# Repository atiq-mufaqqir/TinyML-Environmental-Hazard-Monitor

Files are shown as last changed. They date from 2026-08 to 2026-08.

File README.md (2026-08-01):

# TinyML-Based Indoor Environmental Monitoring System

## Overview

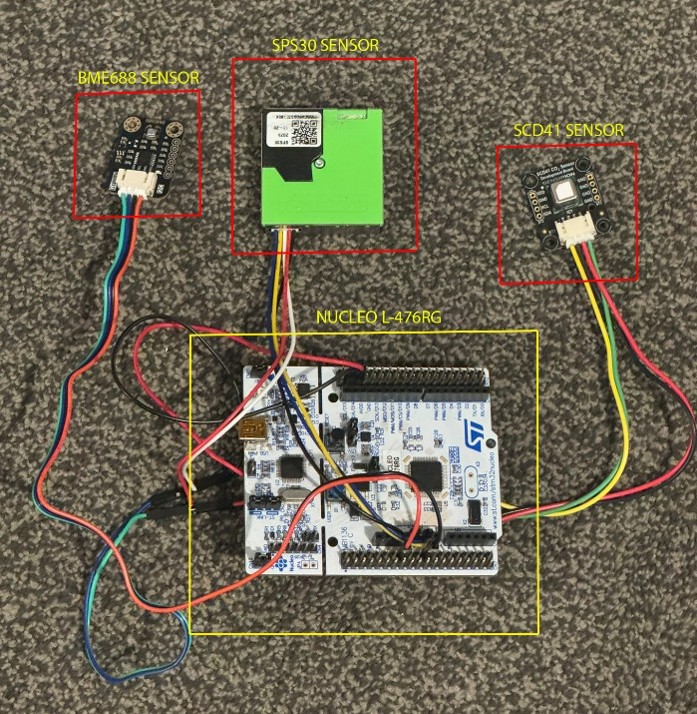
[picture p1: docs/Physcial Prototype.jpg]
Physical Prototype


This project develops a low-cost embedded indoor environmental monitoring system using **multi-sensor fusion and TinyML-based classification**.

The system uses an **STM32 Nucleo-L476RG microcontroller** to collect environmental data from multiple sensors, process the data locally, and classify indoor conditions in real time.

Unlike traditional threshold-based air-quality monitoring systems, this project uses machine learning to identify patterns across multiple environmental parameters and classify different indoor events:

- Normal background conditions
- Cooking activity
- Aerosol spray usage

The trained TinyML model is deployed directly onto the STM32 microcontroller, enabling real-time edge inference without cloud processing.

---

# Key Features

- Real-time environmental monitoring
- Multi-sensor data fusion
- STM32 embedded firmware development
- TinyML neural network deployment
- Local machine learning inference
- UART-based live monitoring
- Dataset collection and processing
- Custom PCB design using KiCad

---

# System Architecture

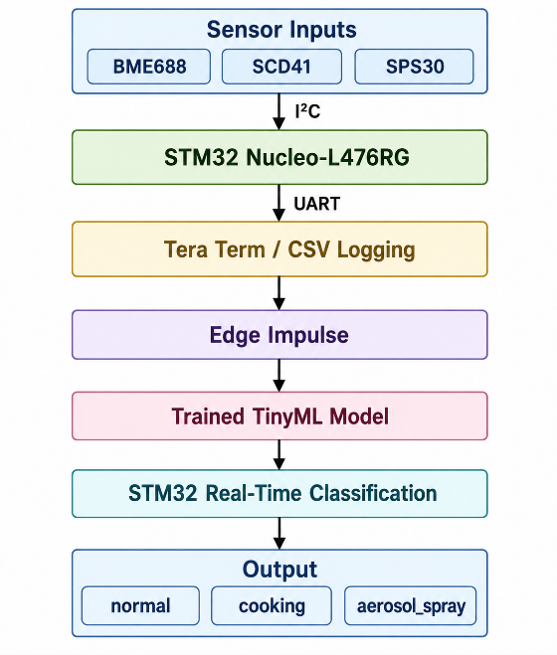
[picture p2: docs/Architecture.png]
System Architecture


# Hardware Components

## STM32 Nucleo-L476RG

The STM32 Nucleo-L476RG was selected as the embedded processing platform.

Features used:

- ARM Cortex-M4 processor
- STM32CubeIDE development environment
- STM32 HAL libraries
- I2C communication
- UART communication
- Embedded TinyML inference

---

# Environmental Sensors

## Bosch BME688

Measurements:

- Temperature
- Humidity
- Pressure
- Gas resistance

Purpose:

- Detect environmental and gas-related changes caused by indoor activities.

---

## Sensirion SCD41

Measurement:

- Carbon dioxide (CO₂)

Purpose:

- Provides ventilation and occupancy-related information.

---

## Sensirion SPS30

Measurements:

- PM1.0
- PM2.5
- PM4.0
- PM10
- Particle number concentration

Purpose:

- Detects particulate changes caused by cooking and aerosol events.

---

# Hardware Communication

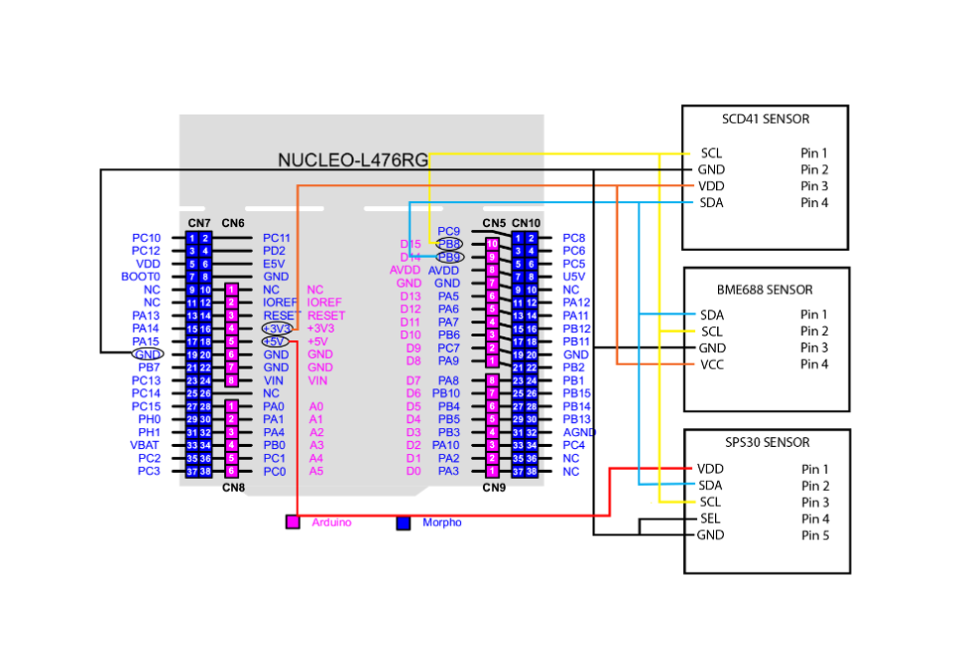
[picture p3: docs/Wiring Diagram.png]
Hardware Connection


| Component | Interface | STM32 Connection |
|---|---|---|
| BME688 | I2C | PB8/PB9 |
| SCD41 | I2C | PB8/PB9 |
| SPS30 | I2C | PB8/PB9 |
| PC Logging | UART | USART2 |

Communication settings:

```
I2C Speed: 100 kHz
UART Baud Rate: 115200
Sampling Interval: 5 seconds
```

---

# Firmware Development

The firmware was developed using:

- STM32CubeIDE
- STM32CubeMX
- STM32 HAL Drivers

## Firmware Workflow

1. Initialise STM32 peripherals
2. Configure I2C and UART communication
3. Detect connected sensors
4. Initialise sensor drivers
5. Read sensor measurements
6. Format sensor data
7. Output data through UART
8. Run TinyML classification

---

# Dataset Collection

A custom dataset was collected in a domestic kitchen environment.

The system was trained to classify three indoor conditions:

| Class | Description |
|---|---|
| Normal | Background indoor conditions |
| Cooking | Frying activity using an induction hob |
| Aerosol | Deodorant and air freshener spray |

## Dataset Summary

| Class | Number of Readings | Duration |
|---|---|---|
| Normal | 5267 | ~439 minutes |
| Cooking | 879 | ~73 minutes |
| Aerosol | 352 | ~29 minutes |

Sampling interval:

```
One reading every 5 seconds
```

---

# TinyML Model Development

The machine learning model was developed using **Edge Impulse**.

## Model Configuration

Input:

- 15 sensor features
- 60 second time windows
- 180 input features

Neural network:

```
Input Layer
      |
Dense Layer (20 neurons)
      |
Dense Layer (10 neurons)
      |
Output Layer (3 classes)
```

Classes:

```
0 - Aerosol
1 - Cooking
2 - Normal
```

---

# Model Performance

## Training Results

| Metric | Result |
|---|---|
| Training Accuracy | 99.06% |
| Validation Accuracy | 100% |
| Validation Loss | 0.0202 |

---

# Embedded Deployment

The trained model was exported as an embedded C/C++ library and deployed onto the STM32 microcontroller.

Deployment results:

| Resource | Usage |
|---|---|
| Model Type | int8 Quantised Neural Network |
| RAM Usage | 1.6 KB |
| Flash Usage | 17.8 KB |
| Estimated Latency | 1 ms |

---

# Real-Time Classification

The final STM32 prototype successfully performed live classification.

Example output:

```
CO2: 650 ppm
PM2.5: 14 ug/m3
Gas Resistance: 42000 Ohm

Prediction:
NORMAL

Confidence:
96%
```

Testing results:

| Condition | Result |
|---|---|
| Normal Room | Correct |
| Cooking | Correct |
| Aerosol Spray | Correct |

---

# PCB Design

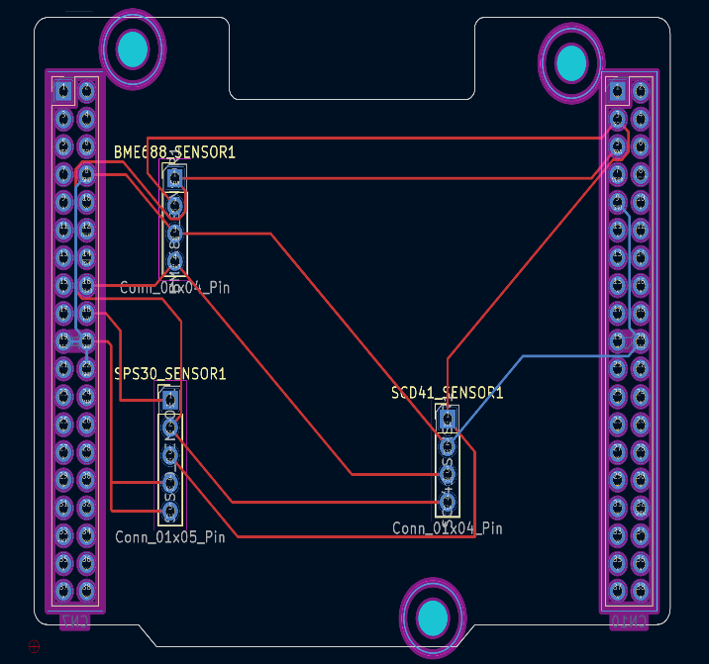
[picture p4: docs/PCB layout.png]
PCB Layout


A custom PCB was designed using **KiCad** to improve hardware integration.

Design process:

- Schematic capture
- Component selection
- PCB layout
- Routing
- Electrical Rule Check (ERC)
- Design Rule Check (DRC)

PCB features:

- STM32 interface
- Sensor connectors
- 3.3V and 5V power distribution
- Modular sensor connections

---

# Repository Structure

```
│
├── Core/
│ ├── Inc/
│ └── Src/
│ └── STM32 application firmware
│
├── Drivers/
│ └── STM32 HAL libraries and sensor drivers
│
├── Release/
│ └── Compiled firmware build files
│
├── docs/
│ └── Project documentation and images
│
├── media/
│ └── Project demonstration images/videos
│
├── ml/
│ ├── Dataset/
│ ├── Edge_Impulse/
│ └── Model training files
│
├── pcb/
│ └── KiCad schematic and PCB design files
│
├── TEST.ioc
│ └── STM32CubeMX configuration file
│
├── .project
├── .cproject
│
├── STM32L476RGTX_FLASH.ld
├── STM32L476RGTX_RAM.ld
│
└── README.md
```

---

# Technologies Used

## Embedded Systems

- STM32 Nucleo-L476RG
- ARM Cortex-M4
- STM32CubeIDE
- STM32 HAL
- I2C
- UART

## Sensors

- Bosch BME688
- Sensirion SCD41
- Sensirion SPS30

## Machine Learning

- TinyML
- Edge Impulse
- Neural Networks
- int8 Quantisation

## Hardware Design

- KiCad
- PCB Design
- Embedded Hardware Integration

---

# Limitations

Current limitations:

- Dataset collected from one indoor environment
- Limited aerosol training samples
- Sensor behaviour may vary between locations
- Not a certified air-quality or safety monitoring device
- PCB designed but not manufactured

---

# Future Improvements

Potential improvements:

- Collect larger datasets from different environments
- Add more indoor activity classes
- Add wireless connectivity (BLE/Wi-Fi)
- Develop mobile monitoring application
- Create battery-powered version
- Manufacture and test the PCB
- Compare against traditional threshold systems

---

# Project Outcome

This project demonstrates the use of **TinyML for intelligent embedded environmental monitoring** by combining:

- Sensor fusion
- Embedded firmware
- Machine learning
- Edge inference
- Hardware design

The final prototype successfully collected environmental data, trained a classification model, deployed the model onto an STM32 microcontroller, and performed real-time indoor condition classification.

---

# Author

Atiq Mufaqqir

## License

This project is intended for educational purposes as part of the ELEC3875 Individual Engineering Project.

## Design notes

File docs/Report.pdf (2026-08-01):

## Table of Contents

## List of Figures

Figure 2-1: System architecture of the TinyML-based indoor environmental monitoring

system | 9
Figure 2-2: Wiring diagram of the STM32 Nucleo-L476RG sensor system | 12

Figure 2-3: Physical prototype of the TinyML indoor environmental monitoring system......13

Figure 2-4: Tera Term output reading sensor values | 15
Figure 2-5: Logged dataset CSV format | 15
Figure 2-6: Firmware initialisation | 16
Figure 2-7: Kitchen Mockup | 16
Figure 2-8: Labelled and cleaned CSV dataset prepared for Edge Impulse | 18
Figure 2-9: Edge Impulse confusion matrix for the trained int8 classifier | 22
Figure 2-10: Tera Term live classification output from the final STM32 prototype | 23
Figure 2-11: KiCad schematic design and PCB layout | 24
Figure 2-12: KiCad 3D view of the proposed PCB design | 25

## List of Tables

Table 2-1: Sensor Operating Ranges | 11
Table 2-2: Sensor role in the sensing platform | 11
Table 2-3: Final Sensor Connections | 12
Table 2-4: STM32 communication configuration | 13
Table 2-5: Dataset collection conditions | 17
Table 2-6: Final labelled dataset summary | 18
Table 2-7: Embedded real-time inference workflow | 20
Table 2-8: Edge Impulse int8 deployment profiling results | 20
Table 2-9: TinyML model training and validation results | 21
Table 2-10: Validation confusion matrix | 22
Table 2-11: Real-time prototype testing results | 23

## 1 INTRODUCTION

### 1.1 Background

People spend a large proportion of their time indoors. Although indoor spaces are often

considered safe, they can contain pollution sources, including cooking, cleaning products,

aerosol sprays, and inadequate ventilation. The United States Environmental Protection

Agency states that indoor air-quality problems are often caused by indoor sources that release

gases or particles, while poor ventilation can allow pollutants to accumulate indoors [1].

Particulate matter is one of the main pollutants considered in this project. Fine particles can

remain suspended in air for long periods and can be inhaled deep into the respiratory system.

The World Health Organization identifies exposure to fine particulate matter as a major

environmental health risk [2]. Cooking is a common indoor source of particulate matter,

particularly during frying, heating, or food preparation. Even when an induction hob is used,

cooking can still produce fine particles that may affect indoor air quality over time [3].

Volatile organic compounds (VOCs) are also relevant because they can be released from

household products such as air fresheners, paints, sprays, and cleaning products. The EPA

notes that VOC concentrations can be higher indoors than outdoors and can be influenced by

product use and ventilation conditions [4]. Aerosol spray usage is therefore a relevant indoor

activity to monitor because it can create short-term changes in gas-related and particle-related

sensor readings.

Carbon dioxide is another important indoor measurement. Although CO₂ is not normally

treated as a direct pollutant at typical indoor levels, increased indoor CO₂ can indicate

reduced ventilation, higher occupancy, or limited air exchange with the outdoor environment

[5]. Monitoring CO₂ together with particulate matter, temperature, humidity, and gas-

resistance data can provide a wider understanding of the indoor environment.

Traditional air-quality monitoring systems often use fixed thresholds. These systems usually

trigger an alarm when a single measurement exceeds a predefined limit. Although useful for

basic monitoring, they do not always identify the cause of an air-quality change. For example,

cooking and aerosol spray events may both increase particle concentration or affect gas-

related readings, even though the sources are different. Previous research explains that air-

quality data often involves several pollutant and environmental variables, and that machine-

learning methods can identify complex relationships within structured sensor datasets [6].

Therefore, because indoor activities can produce overlapping sensor responses, a

classification-based approach may be more useful than fixed thresholds.

This project investigates whether a low-cost embedded device can be made context-aware by

classifying indoor conditions in real time. Machine learning is suitable because indoor

environmental data includes several related variables that change over time. A practical

method is TinyML, where a lightweight machine-learning model is deployed directly onto a

microcontroller for local inference.

### 1.2 Current State of the Art

A key development in embedded environmental monitoring is the use of TinyML. TinyML

allows machine-learning models to run on resource-constrained microcontrollers instead of

relying on cloud processing. This can reduce latency, improve privacy, and allow the system

to operate in real time with limited memory, processing power, and energy. Ray describes

TinyML as a shift from high-power machine-learning systems towards low-end edge devices,

while also highlighting challenges such as accuracy, reliability, and hardware limitations [7].

Recent work has shown that TinyML can be applied to air-quality monitoring. Wardana et al.

demonstrated that TinyML models can be deployed on a low-cost air-quality monitoring

device to perform prediction and data-imputation tasks on a microcontroller [8]. Platforms

such as Edge Impulse also support the training, testing, optimisation, and deployment of

embedded machine-learning models to microcontroller platforms.

However, many low-cost air-quality systems still rely mainly on fixed thresholds. These

systems are simple and affordable, but they provide limited information about the type of

event taking place. Cooking, aerosol spray use, cleaning product use, and poor ventilation

may affect several measurements at the same time and may produce similar sensor responses.

As a result, a fixed-threshold system may detect that an environmental change has occurred,

but it may not reliably classify the source.

### 1.3 Problem Statement

The problem addressed in this project is the need for a low-cost embedded system that can

measure indoor environmental conditions and classify the type of condition in real time.

Existing threshold-based systems can detect when a measurement increases above a set value,

but they may not provide enough context to distinguish between different indoor activities.

This project therefore focuses on developing a prototype system that uses multiple environmental sensors and TinyML classification to identify normal background, cooking,

and aerosol spray conditions.

### 1.4 Aim and Objectives

The aim of this project is to design, implement, and evaluate a TinyML-based embedded

indoor environmental monitoring system that can classify normal background, cooking, and

aerosol spray conditions in real time using data from multiple sensors.

The objectives of this project are:

- To investigate indoor air-quality changes during normal background, cooking, and

aerosol spray conditions.

- To develop an STM32-based embedded device for collecting environmental sensor

data.

- To collect and label datasets for the selected indoor conditions.
- To prepare the collected data for machine-learning training.
- To train and evaluate a TinyML model using Edge Impulse.
- To deploy the trained model onto the STM32 platform for real-time classification.
- To assess the system performance, constraints, and classification results.
- To discuss the limitations of the system and identify possible improvements.

### 1.5 Scope and Limitations

This project focuses on the development of a prototype rather than a certified commercial air-

quality monitor. The system is designed to classify three conditions only: normal background,

cooking, and aerosol spray usage. These classes were selected because they represent

common indoor activities and can produce measurable changes in environmental sensor

readings.

The system does not directly measure every possible indoor pollutant. It should not be

considered a professional regulatory monitoring device, a medical device, or a safety-critical

alarm system. The purpose is to classify indoor conditions based on sensor patterns over time,

rather than to determine whether legal exposure limits have been exceeded.

Several technical issues may also affect the system. These include sensor stability, reliable

sensor integration, dataset size, labelling accuracy, and the delay between an activity ending

and the sensor readings returning to normal. For example, particle or gas readings may

remain elevated for several minutes after cooking or aerosol spray usage, making accurate labelling more difficult. The deployed model must also fit within the memory and processing

constraints of the STM32 microcontroller.

### 1.6 Possible Applications

A TinyML-based indoor monitoring system could be used as an air-quality awareness device

in homes, kitchens, offices, and shared indoor spaces. It could provide ventilation feedback,

support smart kitchen monitoring, or help users understand how everyday activities affect

indoor air quality. With a larger dataset, similar systems could also be useful in busy indoor

environments. It can also be used as hazard monitoring system to detect the signs of early

hazards if trained with proper data.

### 1.7 Project Contribution

The main contribution of this project is the design and implementation of a low-cost STM32-

based indoor environmental monitoring prototype that uses TinyML for real-time

classification. The project also contributes a labelled dataset collected under normal

background, cooking, and aerosol spray conditions. This dataset is used to evaluate whether

low-cost sensors and embedded machine learning can distinguish between overlapping indoor

events.

## 2 TECHNICAL WORK

### 2.1 Literature Review

Wardana et al. [8] demonstrate how TinyML can be used to improve low-cost air quality

monitoring by deploying machine learning models directly on a resource-constrained

microcontroller. Their work is important because it shows that embedded devices can support

predictive and intelligent environmental monitoring while maintaining low power

consumption, low latency, and reduced dependence on cloud processing. The system used

sensor data such as CO₂, temperature, humidity, and electrical power parameters, collected

over a three-month period at 10-minute intervals. The data was pre-processed, standardised,

and scaled so that the models could learn useful patterns despite sensor variation, noise, or

missing readings.

A key feature of Wardana et al.’s work is the use of two TinyML models on a single

microcontroller. One model acted as a predictor for estimating air quality and power-related

parameters, while the second model worked as an imputer to reconstruct missing sensor

values. This is relevant to indoor hazard monitoring because real sensor systems may experience incomplete data, noisy readings, or temporary communication issues. Their use of

a 2D convolutional neural network for prediction and a denoising autoencoder for missing

data reconstruction shows that advanced machine learning techniques can be adapted for low-

power embedded systems. The study also applied post-training quantisation when converting

TensorFlow models to TensorFlow Lite, reducing model size by up to 56.6% without major

performance loss. This supports the feasibility of using TinyML on microcontrollers where

RAM, flash memory, and processing power are limited.

Another relevant study by Arthur et al. [9] compares Edge Impulse and TensorFlow as

TinyML development platforms for maize leaf disease identification. Although the

application is agricultural image classification rather than indoor air quality monitoring, the

paper is relevant because it evaluates the practical workflow required to collect data, train a

model, test performance, and deploy inference on microcontroller-based hardware. The study

used a dataset of 12,344 raw maize leaf images and 7,454 augmented images across five

classes, showing the importance of a clearly labelled and structured dataset for classification

tasks. This directly relates to this project because the indoor monitoring model also depends

on correctly labelled classes such as normal, cooking, and aerosol spray.

Arthur et al. [9] found that TensorFlow offers greater flexibility and control over model

architecture, training parameters, and optimisation. However, it requires more coding

knowledge and has a steeper learning curve. Edge Impulse, in contrast, provides a more user-

friendly workflow for data collection, preprocessing, training, testing, and deployment. This

is useful for embedded TinyML projects because successful deployment is just as important

as model accuracy. Their results showed that TensorFlow achieved slightly higher testing

accuracy of 96.38%, compared with 94.84% for Edge Impulse. However, Edge Impulse

required less memory, using 726.6 KB RAM and 344.7 KB flash compared with 890.5 KB

RAM and 374.4 KB flash for TensorFlow. This highlights an important embedded-system

trade-off: the most accurate model is not always the most suitable if it requires more memory,

processing time, or deployment effort.

Both studies show that TinyML is suitable for real-time monitoring systems where local

inference, low latency, and efficient resource use are required. Wardana et al. [8] provide

evidence that low-cost sensors and TinyML can be combined for context-aware

environmental monitoring, while Arthur et al. [9] highlight the practical trade-offs between

development platforms such as TensorFlow and Edge Impulse. Together, these studies

support the direction of this project, which aims to develop a microcontroller-based indoor environmental hazard monitoring system using multiple sensors and TinyML classification.

The literature suggests that sensor fusion, careful dataset preparation, model optimisation,

and embedded deployment are key requirements for producing a reliable and practical

system.

### 2.2 Overall System Architecture

The final system combined multi-sensor environmental sensing, STM32-based data

acquisition, serial data logging, dataset preparation, model training, and embedded

classification. The system was designed to detect environmental changes caused by indoor

activities and classify them into three conditions: normal background conditions, cooking

activity, and aerosol spray usage.

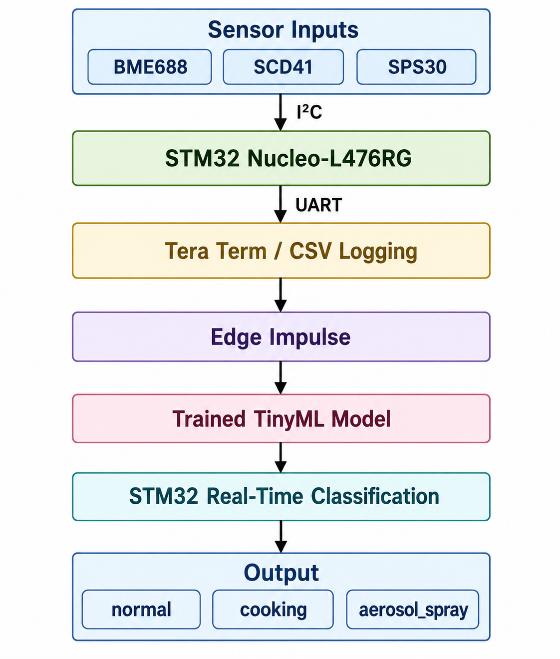
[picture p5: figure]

Figure 2-1: System architecture of the TinyML-based indoor environmental monitoring system

### 2.3 Sensor Selection

The sensors were selected based on measurement relevance, accuracy, communication

interface, firmware support, and compatibility with the STM32 microcontroller. The aim was

to collect environmental features suitable for classifying normal, cooking, and aerosol spray

conditions.

### 2.3.1 Bosch BME688 Environmental and Gas Sensor

The Bosch BME688 was selected because it combines temperature, humidity, pressure, and

gas-resistance sensing in a compact digital device [10]. This reduced hardware complexity

while providing several useful environmental measurements.

Temperature and humidity were relevant because cooking can produce heat and moisture.

Gas resistance was included because it responds to changes in the surrounding gas

composition, which may occur during cooking or aerosol spray use. However, the BME688

does not directly measure individual VOC concentrations [10]. Therefore, gas resistance was

treated as a general gas-response feature rather than a direct VOC measurement. Pressure was

also recorded, although it was not expected to be a main indicator for the target activities.

### 2.3.2 Sensirion SCD41 Carbon Dioxide Sensor

The Sensirion SCD41 was selected to provide carbon dioxide measurement. CO₂

concentration is commonly used as an indicator of ventilation quality and indoor occupancy

[11]. The sensor uses photoacoustic sensing based on non-dispersive infrared principles and

provides an indoor CO₂ range suitable for embedded environmental monitoring [12].

In this project, CO₂ was mainly used to provide ventilation-related context during

classification. Although the SCD41 also outputs temperature and humidity, these were not

used as primary features because the datasheet gives slower response times of approximately

90 seconds for humidity and 120 seconds for temperature[12].

### 2.3.3 Sensirion SPS30 Particulate Matter Sensor

The Sensirion SPS30 was selected to measure airborne particulate matter, which is a major

component of indoor air pollution. It provides PM1.0, PM2.5, PM4.0, and PM10 mass

concentration outputs, as well as particle number concentration measurements [13].

These measurements were important because cooking was expected to increase particulate

concentration, while aerosol spray events could produce different particle patterns depending

on droplet size and ventilation conditions.

### 2.3.4 Multi-Sensor Fusion Justification

The selected sensors provide complementary measurements for indoor event classification.

The BME688 captures environmental and gas-response changes, the SCD41 provides CO₂-

based ventilation context, and the SPS30 detects particulate behaviour. Together, these

features support classification more effectively than a single-sensor system.

The system was designed for event classification rather than laboratory-grade pollutant

measurement. Therefore, the sensors were considered suitable because their operating ranges

match expected domestic indoor conditions.

Sensor | Temperature Range | Humidity Range | Main Measurement Range
BME688 | -40 to +85 °C | 0–100% RH | Pressure: 300–1100 hPa
SCD41 | -10 to +60 °C | 0–95% RH | CO₂: 400–5000 ppm
SPS30 | -10 to +60 °C | 0–95% RH | PM mass: 0–1000 µg/m³

Table 2-1: Sensor Operating Ranges

Sensor | Main measurements used | Contribution to classification
BME688 | Temperature, humidity, pressure, gas resistance | Detects environmental and gas-response changes
SCD41 | CO₂ concentration | Provides ventilation and occupancy-related context
SPS30 | PM mass, particle number, typical particle size | Detects airborne particulate behaviour

Table 2-2: Sensor role in the sensing platform

### 2.4 Hardware Platform and Sensor Integration

Several factors were considered when selecting the microcontroller, including sensor

compatibility, processing capability, memory, low-power operation, TinyML support,

development tools, library availability, cost, and accessibility.

### 2.4.1 Microcontroller Selection

The STM32 Nucleo-L476RG was selected because it provided a suitable balance between

performance, memory, development support, and embedded deployment capability. Its Arm

Cortex-M4 processor provided sufficient processing capacity for continuous environmental

monitoring and TinyML inference. The board also offered suitable flash and RAM for the

firmware and deployed machine-learning model.

The STM32 platform was also compatible with STM32CubeIDE, STM32CubeMX, HAL

libraries, and Edge Impulse, which supported firmware development, debugging, and model

deployment.

### 2.4.2 Electrical Integration and Pin Configuration

The sensors were connected to the STM32 using a shared I²C bus, while UART was used to

transmit live readings to a computer for monitoring and dataset logging through Tera Term.

Component | Supply voltage | Communication | Address | Purpose
BME688 | 3.3 V | I²C | 0x77 | Temperature, humidity, pressure, gas resistance
SCD41 | 3.3 V | I²C | 0x62 | CO₂ concentration
SPS30 | 5 V | I²C | 0x69 | Particulate matter and particle number concentration
PC / Tera Term | USB/UART | UART | N/A | Serial monitoring and data logging

Table 2-3: Final Sensor Connections

The BME688 and SCD41 were powered from the 3.3 V rail, while the SPS30 was powered

from the 5 V output due to its internal fan and optical measurement system. A short cable was

used for the SPS30 connection to reduce noise and communication errors[13].

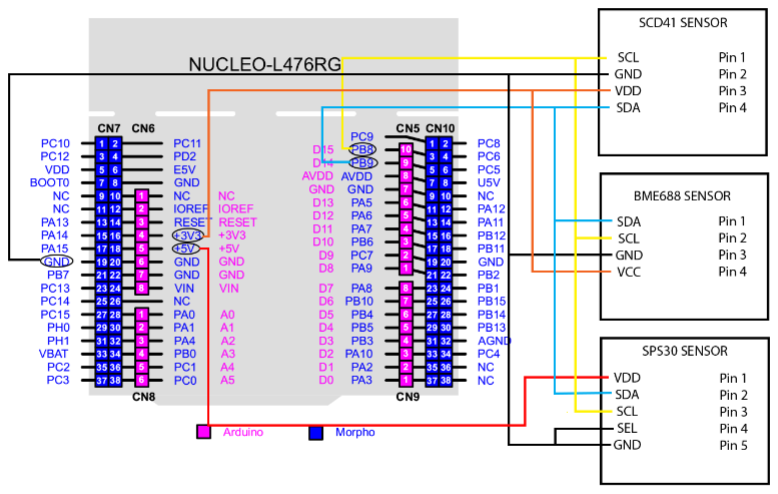
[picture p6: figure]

Figure 2-2: Wiring diagram of the STM32 Nucleo-L476RG sensor system

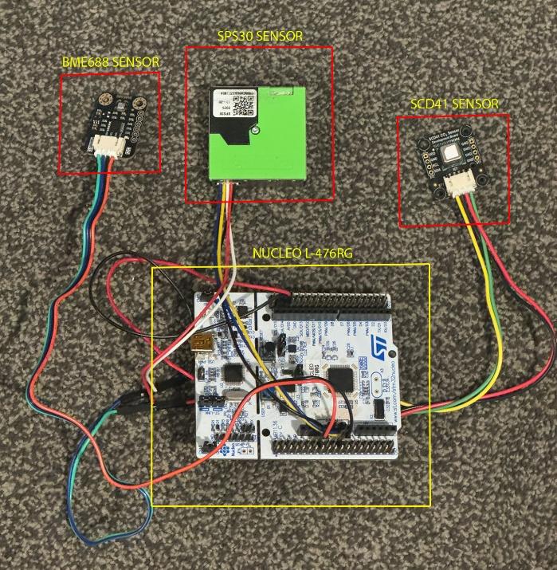
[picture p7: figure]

Figure 2-3: Physical prototype of the TinyML indoor environmental monitoring system

During initial testing, the default STM32CubeMX I²C pin configuration did not match the

physical wiring, which prevented sensor detection. This was resolved by configuring PB8 as

SCL and PB9 as SDA.

Parameter | Value used | Purpose
I²C SDA | PB9 | Shared sensor data line
I²C SCL | PB8 | Shared sensor clock line
I²C speed | 100 kHz | Stable standard-mode communication
UART | USART2, 115200 baud | Serial output to Tera Term

Table 2-4: STM32 communication configuration

### 2.5 Firmware Design and Data Acquisition

The firmware was developed in STM32CubeIDE, with STM32CubeMX used to configure

peripherals and generate the initial HAL-based project structure.

### 2.5.1 Firmware Architecture and Sensor Driver Integration

The firmware followed a sequential start-up structure. This ensured that each sensor was

detected, configured, and started before data logging began. UART messages were printed at

each stage to support debugging and confirm successful initialisation.

After HAL_Init(), the firmware configured the system clock, GPIO, I²C, UART, and RTC

peripherals. I²C was used for the BME688, SCD41, and SPS30 sensors, while USART2

transmitted debugging messages and sensor readings to Tera Term at 115200 baud.

Official sensor drivers were integrated as separate files. The BME688 used the Bosch

bme68x driver, the SCD41 used Sensirion scd4x_i2c and sensirion_i2c_hal functions, and the

SPS30 used the Sensirion SPS30 I²C driver. This modular structure separated the main

program from lower-level sensor communication.

### 2.5.2 Sensor Initialisation and Sampling

At start-up, the firmware first performed an I²C scan using HAL_I2C_IsDeviceReady(). This

checked all 7-bit I²C addresses from 1 to 126 and printed detected device addresses through

UART. This confirmed whether the sensors were correctly connected and powered.

The firmware then initialised the BME688, SCD41, and SPS30 sensors, stopped any previous

SCD41 measurement mode, started SCD41 periodic measurement, woke the SPS30, and

started SPS30 measurement in floating-point mode. A 15-second delay was included before

logging began to reduce unstable start-up readings.

A 5000 ms sampling interval was implemented using HAL_GetTick(). This produced one

structured data row every five seconds. The interval was suitable because indoor air-quality

events such as cooking and aerosol spray usage change over seconds rather than milliseconds.

It also matched the slower update rate of the SCD41.

During each acquisition cycle, the firmware read SPS30 particulate data, performed a

BME688 measurement, checked whether SCD41 data were ready, and then read the CO₂

value. The readings were combined into one structured UART output row.

### 2.5.3 UART Logging and Serial Data Output

Tera Term was used to monitor, timestamp and save the UART output from the STM32. The

firmware transmitted readings in a fixed comma-separated format so that each acquisition

cycle produced one structured row.

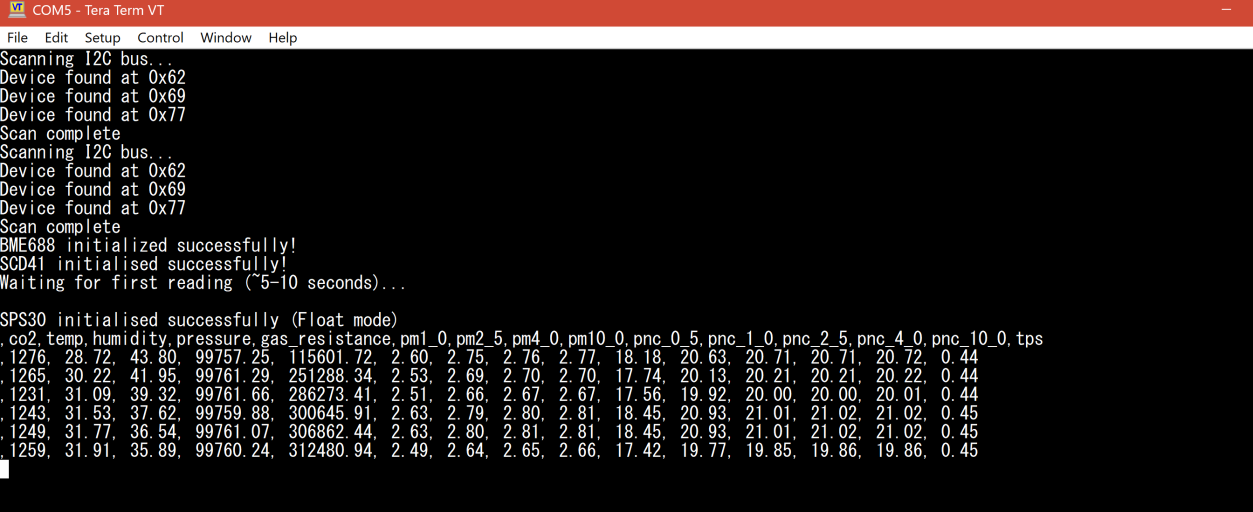
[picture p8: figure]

Figure 2-4: Tera Term output reading sensor values

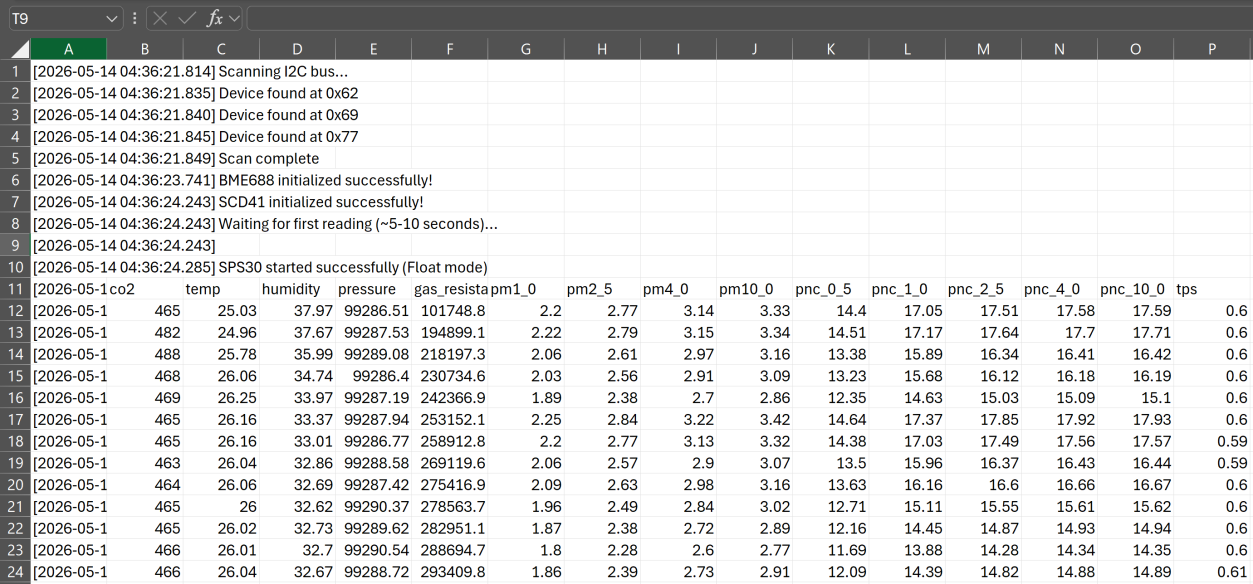
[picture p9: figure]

Figure 2-5: Logged dataset CSV format

The firmware output was kept as raw serial sensor data to reduce microcontroller processing

load. Any later cleaning, formatting, and labelling were completed outside the firmware

stage.

### 2.5.4 Firmware Validation

The firmware was validated in stages. First, the STM32 project was compiled and flashed

successfully. UART output was then tested using printf() through USART2. The I²C scan was

used to confirm that the sensors were visible on the shared bus.

After sensor detection, each sensor was checked using live readings. Final validation

involved observing sensor responses during normal background conditions, cooking, and

aerosol spray experiments. The readings changed as expected, confirming that the system was

suitable for repeatable data acquisition.

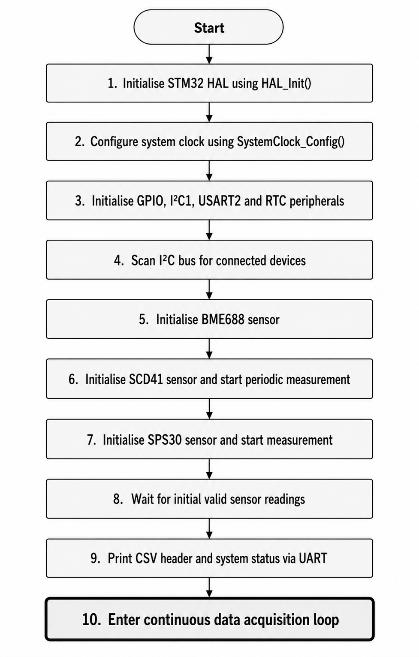
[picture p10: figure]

Figure 2-6: Firmware initialisation

### 2.6 Dataset Collection Procedure

The aim of dataset collection was to obtain realistic sensor data for training and testing a

TinyML model to classify three indoor conditions: normal background, cooking, and aerosol

spray. Data were collected under different activity and ventilation conditions to improve

dataset variety.

### 2.6.1 Experimental Environment and Sensor Placement

Dataset collection was carried out in a domestic kitchen measuring 3.96 m × 3.58 m. The

sensing platform was positioned 0.86 m above the floor, while the induction hob height was

0.90 m. The diagonal distance between the sensor platform and the hob was 0.89 m. Although

this was not a final practical mounting position, it provided a controlled and repeatable

location for experimental data collection.

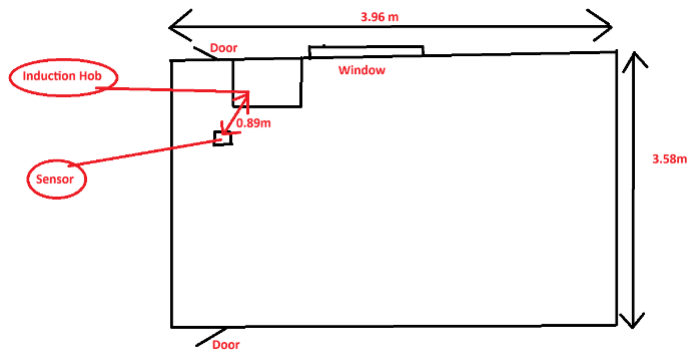
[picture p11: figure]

Figure 2-7: Kitchen Mockup

An induction hob was used for all cooking experiments. Unlike gas appliances, induction

cooking does not directly produce combustion emissions. Therefore, the measured changes during cooking were mainly associated with cooking aerosols, steam, oil vapour, heat, and

particulate generation. During each session, the kitchen extractor was kept off and internal

doors remained closed to reduce uncontrolled airflow. The same kitchen, sensor position,

hob, sampling interval, sensor setup, and logging method were used across all sessions.

### 2.6.2 Dataset Sessions and Experimental Conditions

Six datasets were collected under different activity and ventilation conditions.

Dataset | Activity | Window state | Time period | Label
D1 | Normal background | Open | Night | normal
D2 | Normal background | Closed | Night | normal
D3 | Cooking | Open | Day/evening | cooking
D4 | Cooking | Closed | Day/evening | cooking
D5 | Aerosol spray | Open | Day/evening | aerosol
D6 | Aerosol spray | Closed | Day/evening | aerosol

Table 2-5: Dataset collection conditions

For cooking and aerosol sessions, recording began under normal background conditions. The

target activity was introduced approximately 10 to 15 minutes later. The normal datasets were

used to establish baseline kitchen conditions when no major pollution-generating activity was

present.

The cooking datasets involved frying steak with butter for approximately 10 to 15 minutes.

This activity was selected because it produces realistic cooking-related changes, including

fine particles, oil vapour, heat, and moisture.

The aerosol datasets were collected using deodorant spray and air freshener. Both products

were grouped into one aerosol class because the aim was to detect short aerosol-related

events rather than classify individual products. Data collection continued until readings

returned close to normal background levels.

### 2.6.3 Sampling Interval and Sensor Stabilisation

Data were sampled every five seconds. This interval captured gradual indoor air-quality

changes while limiting data redundancy and file size. It also matched the SCD41 update rate,

which provides new readings approximately every five seconds.

The first 10 minutes of readings were discarded after system start-up to reduce the effect of

unstable sensor behaviour and improve dataset consistency.

### 2.6.4 Data Logging, Cleaning, and Labelling

Raw data were collected from the STM32 through UART using TeraTerm. Timestamps and

CSV formatting were added during serial logging by TeraTerm. The recorded data were then

cleaned and labelled for machine learning preparation. The label column was used by Edge

Impulse as the target output for supervised machine learning.

Each CSV file was labelled according to the dominant experimental condition. For cooking

and aerosol datasets, the label included the active event period and the recovery period where

sensor readings remained clearly elevated. This matched the practical aim of detecting recent

or ongoing environmental events rather than only identifying the exact moment when the

source was active.

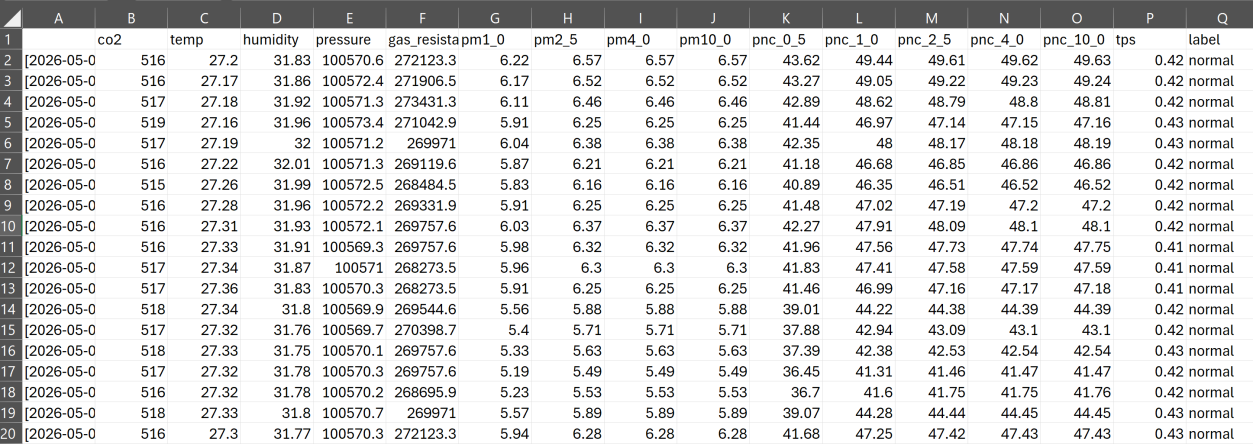
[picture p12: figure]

Figure 2-8: Labelled and cleaned CSV dataset prepared for Edge Impulse

Class | Number of readings | Approx. duration
normal | 5267 | 439 minutes
cooking | 879 | 73 minutes
aerosol | 352 | 29 minutes

Table 2-6: Final labelled dataset summary

### 2.6.5 Recovery Period and Label Assignment

After cooking stopped, the sensor readings did not immediately return to normal. A recovery

period of approximately 15 to 20 minutes was observed, although this was shorter in aerosol

and when windows were open. During this time, particulate matter, humidity, gas response,

and other environmental indicators gradually returned towards background levels.

Early recovery samples were labelled as cooking while the sensor response remained clearly

elevated. Once readings approached the normal baseline, samples were labelled as normal.

Ambiguous transition samples were excluded where necessary to reduce label noise.

The same approach was used for aerosol recordings. Although the spray event was short,

sensor readings remained affected after spraying. Samples were labelled as aerosol while the

response remained clearly different from normal background conditions.

### 2.7 TinyML Model Development and Training

The TinyML model was developed in Edge Impulse using the cleaned and labelled sensor

dataset. The aim was to train a lightweight classifier for three indoor conditions: normal,

cooking, and aerosol.

The impulse used a time-series input block with 15 sensor axes. A 60,000 ms window size

and 60,000 ms window increase were selected. Since the sampling interval was five seconds,

each window contained 12 readings. This produced 180 input features per inference window.

A Raw Data processing block was used because the input values were already structured

environmental measurements. StandardScaler normalisation was applied to reduce the effect

of different feature scales, such as pressure, gas resistance, CO₂, and particulate

measurements.

The classifier used a neural network with an input layer of 180 features, followed by dense

layers of 20 and 10 neurons. The output layer contained three classes: aerosol, cooking, and

normal. The model was trained for 100 cycles, with a learning rate of 0.0005, batch size of

32, and a validation split of 20%.

The model was profiled as an int8 quantised neural network. This was suitable for TinyML

deployment because int8 quantisation reduces memory use and processing demand compared

with a float32 model. This allowed the trained classifier to be deployed to the STM32

microcontroller for local inference.

### 2.8 Embedded Deployment and Real-Time Classification

After training, the model was exported from Edge Impulse as an embedded C/C++ library

and added to the STM32CubeIDE project. The existing sensor acquisition firmware was then

extended so that live readings could be passed into the classifier.

The live input format had to match the training format. Each sensor cycle produced 15

values, which were stored in a fixed buffer.

Once the buffer was full, the values were passed to the Edge Impulse classifier. The model

returned probability scores for the three classes, and the firmware selected the class with the

highest score as the predicted condition. The predicted class and confidence values were

printed through UART and viewed on a serial terminal.

Stage | Function
Sensor acquisition | Read live BME688, SCD41, and SPS30 data
Buffering | Store readings
Inference | Run the Edge Impulse classifier on STM32
Output | Print predicted class through UART

Table 2-7: Embedded real-time inference workflow

The classifier successfully ran on the STM32 prototype. This confirms that the project was

not limited to offline model training; the trained TinyML model was deployed for local

embedded inference.

### 2.9 Embedded Resource Usage

The model was also checked using the Edge Impulse deployment/profile information.

Deployment metric | Quantised int8 result
Model format | Quantised int8 neural network
Estimated latency | 1 ms
Total RAM usage | 1.6K
Classifier RAM usage | 1.0K
Raw data RAM usage | 0.6K
Classifier flash / ROM usage | 17.8K
Reported accuracy | 98.02%
Edge Impulse target used for estimate | ST STM32N6 Cortex-M55 800 MHz

Table 2-8: Edge Impulse int8 deployment profiling results

The profiling results show that the model is lightweight for embedded TinyML deployment.

The quantised int8 version required only 1.6K RAM and 17.8K flash/ROM for the classifier,

with an estimated inference latency of 1 ms on the selected Edge Impulse STM32N6 target.

Although this target is not identical to the STM32 Nucleo-L476RG used in the project, the

result still provides useful evidence that the model has low memory and processing

requirements.

### 2.10 System Performance Evaluation

### 2.10.1 Model Training and Validation Performance

The model achieved strong performance in Edge Impulse. The training accuracy was

approximately 99.06%, while the int8 validation accuracy was 100% with a validation loss

of 0.0202.

Metric | Result
Total data collected | 9 h 1 min 30 s
Train/test split | 80% / 20%
Training samples | 399
Test samples | 101
Training windows | 398
Number of classes | 3
Classes | aerosol, cooking, normal
Window size | 60,000 ms
Input layer features | 180
Training accuracy | 99.06%
Validation accuracy | 100%
Int8 validation loss | 0.0202

Table 2-9: TinyML model training and validation results

These results show that the model separated the three classes well within the collected

dataset. However, the result should not be overgeneralised because the data were collected

using one prototype setup and a limited set of indoor conditions.

### 2.10.2 Confusion Matrix Analysis

Actual class | Predicted aerosol | Predicted cooking | Predicted normal
Aerosol | 3 | 0 | 0
Cooking | 0 | 10 | 0
Normal | 0 | 0 | 67

Table 2-10: Validation confusion matrix

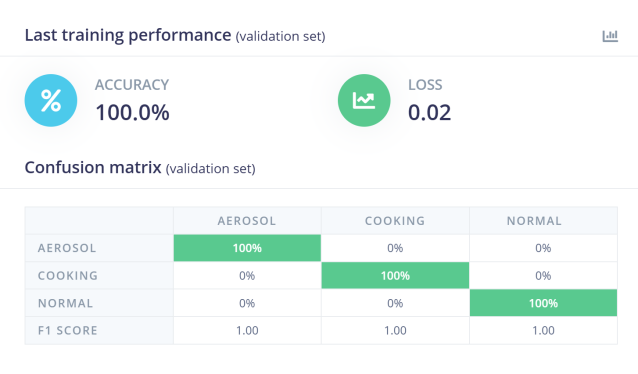
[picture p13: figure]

Figure 2-9: Edge Impulse confusion matrix for the trained int8 classifier

The confusion matrix shows that all validation samples were classified correctly. The model

correctly identified 67 normal, 10 cooking, and 3 aerosol windows. In the validation set, all

samples were classified correctly. However, the separate held-out test set showed two aerosol

windows being classified as cooking. This suggests that the model performs strongly overall,

but aerosol detection is less robust than normal and cooking classification because the aerosol

class has fewer examples.

This is a positive result because cooking and aerosol spray can both affect particle-related

readings. The result suggests that the model used the combined multi-sensor pattern rather

than relying on one measurement only. However, the aerosol class had only three validation

samples, so more aerosol data would be needed to prove stronger reliability.

### 2.10.3 Real-Time Prototype Testing

The deployed model was tested using live sensor readings from the STM32 prototype.

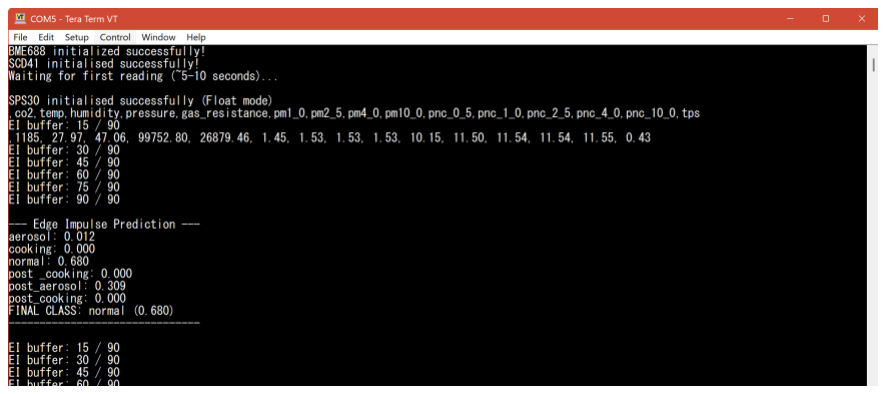
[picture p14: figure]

Figure 2-10: Tera Term live classification output from the final STM32 prototype

Test condition | Expected class | Prototype output | Result
Normal room | normal | normal | Correct
Cooking / frying | cooking | cooking | Correct
Aerosol spray | aerosol | aerosol | Correct

Table 2-11: Real-time prototype testing results

The prototype printed predictions through UART, allowing the output to be monitored in real

time. Normal conditions were classified as normal, cooking as cooking, and aerosol spray as

aerosol.

After spraying stopped, the system sometimes continued to output aerosol. This is reasonable

because the sensors detect the air condition, not the user action itself. Aerosol particles and

gas-related changes can remain in the air after spraying, especially with limited ventilation.

Therefore, the continued aerosol output during recovery indicates that the air was still

affected.

### 2.10.4 Dataset and Evaluation Limitations

The main limitation is dataset variety. The data were collected using one hardware setup and

mainly one indoor environment. Room size, sensor position, ventilation, cooking method, and

aerosol product type could all affect the readings.

The class balance was also limited. The normal class had much more data than the aerosol

class, and the aerosol validation result was based on only three windows. This reduces

confidence in the robustness of aerosol detection.

Labelling was another challenge because cooking and aerosol effects do not stop immediately

when the activity stops. Recovery samples can still contain elevated readings, so exact label

boundaries are difficult to define.

### 2.11 PCB Design Using KiCad

KiCad was used to design a custom printed circuit board (PCB) for the embedded monitoring

system. The purpose of the PCB design was to improve integration, reliability, and

organisation of the hardware compared with the initial wired prototype, which was mainly

used for testing and debugging.

The PCB was designed to interface the STM32 microcontroller with the three environmental

sensors used in the project. The design process included schematic capture, footprint

assignment, component placement, and PCB routing. Net labels were used to improve

schematic readability and reduce wiring complexity within the design. Connector headers

were also included so that the sensors could be removed, replaced, or repositioned during

testing without permanently soldering them to the board.

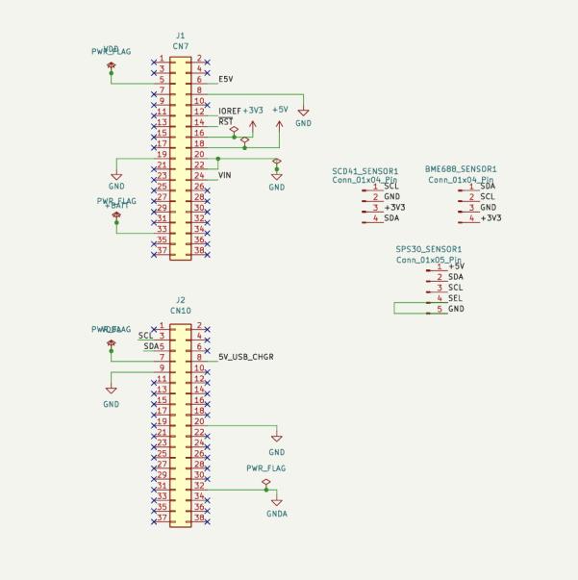
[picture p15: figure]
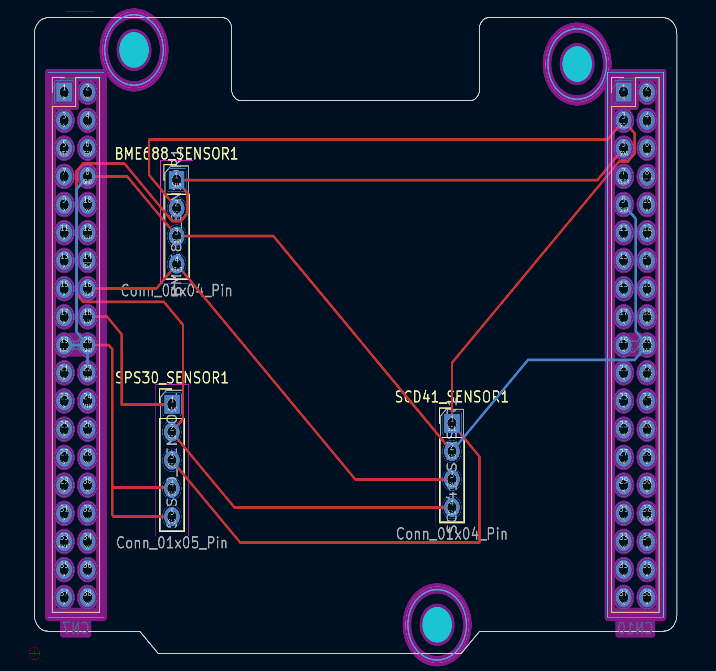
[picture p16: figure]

Figure 2-11: KiCad schematic design and PCB layout

Component placement was considered carefully to reduce routing complexity and minimise

unnecessary trace lengths. Shorter traces helped produce a cleaner layout and reduced the risk

of unwanted noise pickup on signal lines. Power distribution was also considered because the

system used both 3.3 V and 5 V supplies. The BME688 and SCD41 were supplied from 3.3

V, while the SPS30 required a 5 V supply.

Although the PCB was not manufactured within the project timescale, the design was

checked using KiCad’s Electrical Rule Check and Design Rule Check tools. Both checks

passed with 0 errors, indicating that the schematic connections and PCB layout met the

defined design constraints. However, because the board was not physically fabricated,

practical validation such as assembly testing, signal verification, and long-term reliability

testing could not be completed.

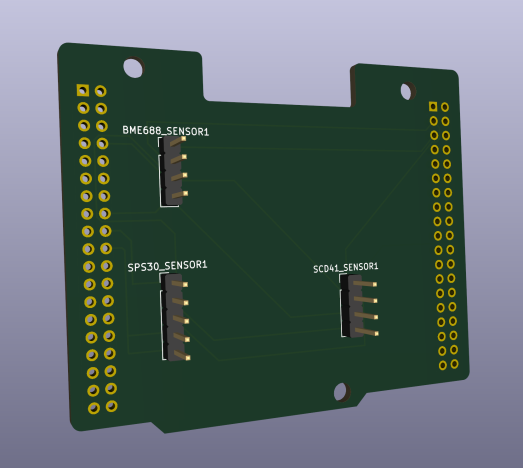
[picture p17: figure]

Figure 2-12: KiCad 3D view of the proposed PCB design

PCB design provided a practical foundation for future hardware development if the system

were to be manufactured and tested as a complete standalone device.

### 2.12 Professional, Ethical, Risk, Security and Inclusion Considerations

Professional, ethical, risk, security, and inclusion factors were considered because the system

monitors indoor environmental conditions that may influence user decisions about ventilation

and air quality. The project has a positive societal purpose because it supports awareness of

indoor changes caused by common activities such as cooking and aerosol spray usage. By

running the TinyML model locally on the STM32, the system also reduces the need for cloud

processing, which can lower network dependence and improve data privacy.

Ethical and safety considerations affected the project scope. More dangerous hazards such as

fire, smoke, or gas leaks were not deliberately tested because they would create unnecessary

safety risks. Instead, the project focused on safer and realistic indoor conditions: normal

background, cooking, and aerosol spray. The system is therefore presented as a prototype for

environmental classification, not as a certified safety alarm, medical device, or regulatory air-

quality monitor.

Several risks were managed during development. Sensor communication risk was reduced by

testing each sensor separately, using an I²C scan, and validating live readings before data

collection. Dataset risk was managed by collecting data under different conditions, removing

unstable start-up readings, and excluding ambiguous transition samples where necessary.

Labelling was also a challenge because cooking and aerosol effects remained in the air after

the activity stopped. This was managed by labelling recovery periods according to the

observed sensor response rather than only the action timing.

Deployment risk was considered because the model had to fit within STM32 memory and

processing constraints. This was reduced by using an int8 quantised model and checking

Edge Impulse profiling results. However, the full firmware memory usage should still be

checked using the STM32CubeIDE build report because the complete system includes sensor

drivers, HAL libraries, UART output, and application code.

Security and privacy risks were limited because the prototype used local inference and

collected only environmental sensor readings. However, UART logs should still be handled

carefully because they may reveal activity patterns. If the system were developed further with

wireless connectivity, secure authentication, encryption, and clear data-handling rules would

be required.

Inclusion was considered using low-cost, accessible hardware and simple output classes such

as normal, cooking, and aerosol. Future versions should avoid relying only on Serial output

and should provide clear text, symbols, or sound feedback. Further testing in different homes,

room sizes, ventilation conditions, and cooking styles would also improve fairness and

reliability across different users.

## 3 CONCLUSION

This project achieved its main aim of developing a TinyML-based embedded system for real-

time classification of indoor environmental conditions. The final prototype combined

environmental sensing, embedded firmware, dataset collection, machine-learning training,

and microcontroller deployment into one working system. It demonstrated that a low-cost

embedded platform could move beyond simple air-quality monitoring and provide more

meaningful classification of indoor events.

The main finding is that indoor activities such as cooking and aerosol spray usage produce

patterns across several environmental measurements rather than changes in only one parameter. This made a multi-sensor and machine-learning approach more suitable than a

fixed-threshold method. The system was able to use combined sensor behaviour to

distinguish between normal background conditions, cooking, and aerosol spray. This supports

the idea that TinyML can improve context awareness in small, embedded monitoring devices.

The collected dataset was used to train and validate a three-class model in Edge Impulse. The

model achieved strong results within the collected dataset, with high training performance

and correct classification of the validation samples. The confusion matrix showed that the

model could separate the three target classes without misclassification during validation. This

indicates that the selected features and time-window approach were appropriate for the

classification task.

The model was also deployed successfully onto the STM32 microcontroller, which confirmed

that the project was not only a software-based machine-learning exercise. Live sensor

readings were collected, buffered, classified locally, and output through UART. This showed

that real-time inference was possible on the embedded prototype. The low model memory

usage also supported the suitability of the approach for resource-constrained hardware.

However, the results must be interpreted carefully. The dataset was collected in one domestic

environment using one hardware arrangement and a limited number of test conditions. As a

result, the trained model may not generalise reliably to all rooms, cooking styles, ventilation

conditions, or aerosol products. The aerosol class was also smaller than the other classes, so

further data collection would be needed to improve balance and reliability. Another limitation

was the difficulty of labelling recovery periods, because the air remained affected after the

activity itself had stopped.

Overall, the project shows that embedded TinyML can be used to classify indoor

environmental conditions locally and effectively within a prototype system. The work

provides a useful foundation for future development of context-aware indoor monitoring

devices. Future improvements should include a larger and more balanced dataset, testing in

different environments, comparison with threshold-based methods, full firmware memory

analysis, and physical manufacture and validation of the PCB design.

## 4 REFLECTION

This project has been a significant learning experience because it developed from an

uncertain initial idea into a more focused and technically challenging embedded TinyML

system. At the beginning, my original project idea was an IoT greenhouse monitoring system.

However, after discussions with my supervisor and reflection on my own interests and career

direction, I decided to change the project to TinyML for Indoor Environmental Hazard

Monitoring. This was an important turning point because it aligned the project more closely

with embedded systems, machine learning, sensor integration, and real-world environmental

monitoring.

One of the main challenges at the start was the lack of clarity in the project scope. I initially

had a broad idea of detecting indoor hazards, but I did not fully understand what the system

should classify, which sensors were required, or how TinyML could be applied practically.

Through research and supervisor feedback, I gradually refined the project from a general

hazard detection concept into a safer and more realistic context-aware classification system.

This helped me understand the importance of defining measurable objectives rather than

starting with a vague system outcome.

A major lesson I learned was the importance of project planning and risk management.

Creating the Gantt chart helped me break the project into stages such as research, hardware

selection, sensor integration, data collection, TinyML development, testing, and final

documentation. Although the project direction changed early on and I faced delays due to

illness, the planning process helped me recover and restructure the work. It also showed me

that engineering projects rarely follow the original plan exactly, so flexibility and continuous

adjustment are essential.

Technically, this project pushed me outside my comfort zone. I had limited experience with

machine learning, STM32 development, and embedded sensor integration before starting. To

address this, I spent time learning the basics of TinyML, STM32CubeIDE, STM32CubeMX,

I2C communication, UART debugging, and sensor drivers. As the project progressed, I

became more confident in configuring peripherals, testing communication with sensors, and

debugging embedded software issues. For example, resolving problems such as I2C pin

mapping and floating-point printing in UART output improved my understanding of low-

level embedded constraints.

The sensor integration stage was one of the most valuable parts of the project. Working with

sensors such as the BME688, SCD41, SPS30, and MLX90614 helped me understand how

different environmental parameters can support classification. I learned that indoor air quality

cannot be reliably judged from one variable alone. Instead, changes in temperature, humidity,

CO₂, particulate matter, and gas resistance need to be considered together. This strengthened

my understanding of sensor fusion and showed why TinyML can be more suitable than

simple threshold-based detection in noisy indoor environments.

The project also improved my ability to critically evaluate design decisions. Initially, I

considered direct hazard scenarios such as fire or gas leak detection, but supervisor feedback

made me recognise the safety and ethical risks of simulating dangerous events. As a result, I

refined the scope to focus on safe, observable indoor conditions such as normal air, cooking

activity, and poor air quality indicators. This made the project safer, more realistic, and more

academically appropriate. It also helped me understand that engineering decisions must

consider not only technical feasibility but also user safety, ethics, and responsible

deployment.

Another important learning outcome was the role of data quality in machine learning systems.

I realised that the TinyML model would only be as reliable as the data used to train it. This

made structured data collection a critical part of the project. I had to think carefully about

sampling intervals, labels, environmental conditions, and consistency across readings. This

changed my view of machine learning from simply “training a model” to a full engineering

process involving sensing, preprocessing, feature selection, deployment constraints, and

evaluation.

The project also developed my practical engineering skills beyond software. Learning KiCad

and beginning a PCB design helped me understand how a prototype can move closer to a

professional embedded system. Breadboard wiring was useful for testing, but it also

introduced issues such as wiring complexity and reduced reliability. Designing a PCB made

me think more carefully about component placement, routing, power distribution, and

manufacturability. This was useful because it connected the project to real industry practices.

From a professional development perspective, the project helped me improve my

independence and problem-solving skills. Many problems did not have immediate solutions,

so I had to research datasheets, examine drivers, test hardware step by step, and make design

decisions based on evidence. I also learned the importance of documenting progress through weekly journal entries, as this made it easier to reflect on decisions, justify changes, and track

development over time.

Overall, this project has improved my confidence in embedded systems, sensor-based design,

and TinyML deployment. It taught me that successful engineering work requires more than

building a working prototype; it also requires clear scope, safe design decisions, critical

analysis, reliable data, and evidence-based evaluation. Although the project began with

uncertainty and several changes, these challenges helped strengthen the final direction. The

experience has given me practical skills that are relevant to embedded systems,

manufacturing engineering, product development, and intelligent monitoring systems.

## REFERENCES

[1] United States Environmental Protection Agency, “Introduction to Indoor Air Quality,”

EPA, Mar. 19, 2026. [Online]. Available: https://www.epa.gov/indoor-air-quality-

iaq/introduction-indoor-air-quality. Accessed: May 15, 2026.

[2] World Health Organization, WHO Global Air Quality Guidelines: Particulate Matter

(PM2.5 and PM10), Ozone, Nitrogen Dioxide, Sulfur Dioxide and Carbon Monoxide.

Geneva, Switzerland: World Health Organization, 2021. [Online]. Available:

https://www.who.int/publications/i/item/9789240034228. Accessed: May 15, 2026.

[3] Health Canada, “Factsheet: Cooking and Indoor Air Quality,” Government of Canada,

Jan. 12, 2021. [Online]. Available: https://www.canada.ca/en/health-

canada/services/publications/healthy-living/factsheet-cooking-and-indoor-air-

quality.html. Accessed: May 15, 2026.

[4] United States Environmental Protection Agency, “Volatile Organic Compounds’

Impact on Indoor Air Quality,” EPA, Jul. 24, 2025. [Online]. Available:

https://www.epa.gov/indoor-air-quality-iaq/volatile-organic-compounds-impact-

indoor-air-quality. Accessed: May 15, 2026.

[5] United States Environmental Protection Agency, “Can I Measure Carbon Dioxide

(CO₂) Indoors to Get Information on Ventilation?” EPA, Aug. 13, 2025. [Online].

Available: https://www.epa.gov/indoor-air-quality-iaq/can-i-measure-carbon-dioxide-

co2-indoors-get-information-ventilation. Accessed: May 15, 2026.

[6] L. Miranda, C. Duc, N. Redon, J. Pinheiro, B. Dorizzi, J. Montalvao, M. Verriele, and
J. Boudy, “Automatic detection of indoor air pollution-related activities using metal-

oxide gas sensors and the temporal intrinsic dimensionality estimation of data,”

Indoor Environments, vol. 1, no. 3, Art. no. 100026, 2024, doi:

10.1016/j.indenv.2024.100026.

[7] P. P. Ray, “A review on TinyML: State-of-the-art and prospects,” Journal of King

Saud University – Computer and Information Sciences, vol. 34, no. 4, pp. 1595–1623,

2022, doi: 10.1016/j.jksuci.2021.11.019.

[8] N. K. Wardana, J. W. Gardner, and S. A. Fahmy, “TinyML models for a low-cost air

quality monitoring device,” IEEE Sensors Letters, vol. 7, no. 11, Art. no. 6007804,

2023.

[9] E. A. E. Arthur, F. A. Wulnye, D. A. N. Gookyi, K. O. B. O. Agyekum, P. Danquah,

and R. Gyaang, “Edge Impulse vs TensorFlow: A comparative analysis of TinyML platforms for maize leaf disease identification,” in 2024 Conference on Information

Communications Technology and Society (ICTAS), 2024, pp. 1–6, doi:

10.1109/ICTAS59620.2024.10507119.

[10] Bosch Sensortec, BME688 Datasheet: Digital Low Power Gas, Pressure,

Temperature & Humidity Sensor with AI, Doc. BST-BME688-DS000-03, Rev. 1.3,

Feb. 2024. [Online]. Available: https://www.bosch-

sensortec.com/media/boschsensortec/downloads/datasheets/bst-bme688-ds000.pdf.

Accessed: May 15, 2026.

[11] Health and Safety Executive, “Using CO₂ monitors – Ventilation in the

Workplace.” [Online]. Available: https://www.hse.gov.uk/ventilation/using-co2-

monitors.htm. Accessed: May 15, 2026.

[12] Sensirion AG, Datasheet SCD4x CO₂ Sensor, Version 1.7, Apr. 2025.

[Online].Available:

https://sensirion.com/media/documents/48C4B7FB/67FE0194/CD_DS_SCD4x_Data

sheet_D1.pdf. Accessed: May 15, 2026.

[13] Sensirion AG, Datasheet SPS30 Particulate Matter Sensor for Air Quality

Monitoring and Control, Version 2.0, Jun. 2023. [Online]. Available:

https://sensirion.com/media/documents/8600FF88/64A3B8D6/Sensirion_PM_Sensors

_Datasheet_SPS30.pdf. Accessed: May 15, 2026.

## PROJECT PORTFOLIO

This portfolio presents three review documents that were prepared and shared with the

supervisor during the project. The content included here is a verbatim reproduction of the

original submissions, with no modifications. All dates and information are accurate and

correspond to the materials provided to the supervisor, as referenced on the second page of

this final submission and repeated below for clarity. This section serves as a record of

ongoing progress and documented feedback throughout the project.

Document Name | Date and Means of Approval
Review Document 1 | 19/11/2025, Approved verbally
Review Document 2 | 03/12/2025, Approved verbally
Review Document 3 | 03/02/2026, Approved verbally
Review Document 4 | 17/02/2026, Approved verbally
Review Document 5 | 05/03/2026, Approved verbally
Review Document 6 | 17/03/2026, Approved verbally
Review Document 7 | 24/03/2026, Approved verbally
Review Document 8 | 30/04/2026, Approved verbally
Review Document 9 | 08/05/2026, Approved verbally

Review Document 10

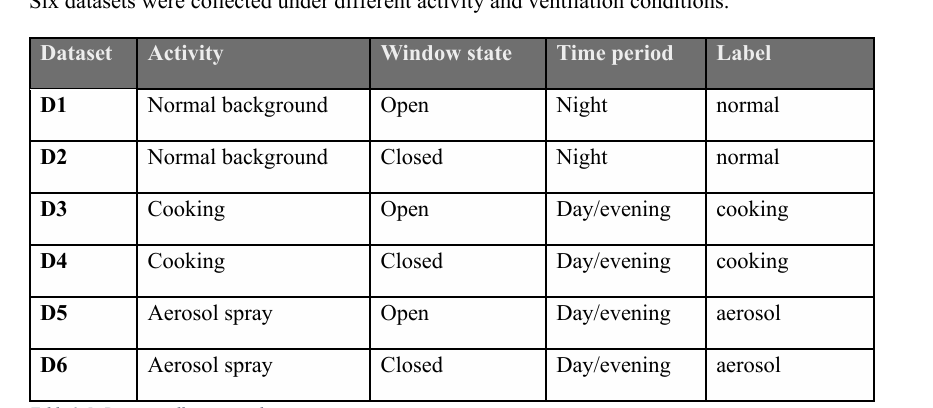
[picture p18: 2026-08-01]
ml/Screenshot 2026-05-18 070757.png

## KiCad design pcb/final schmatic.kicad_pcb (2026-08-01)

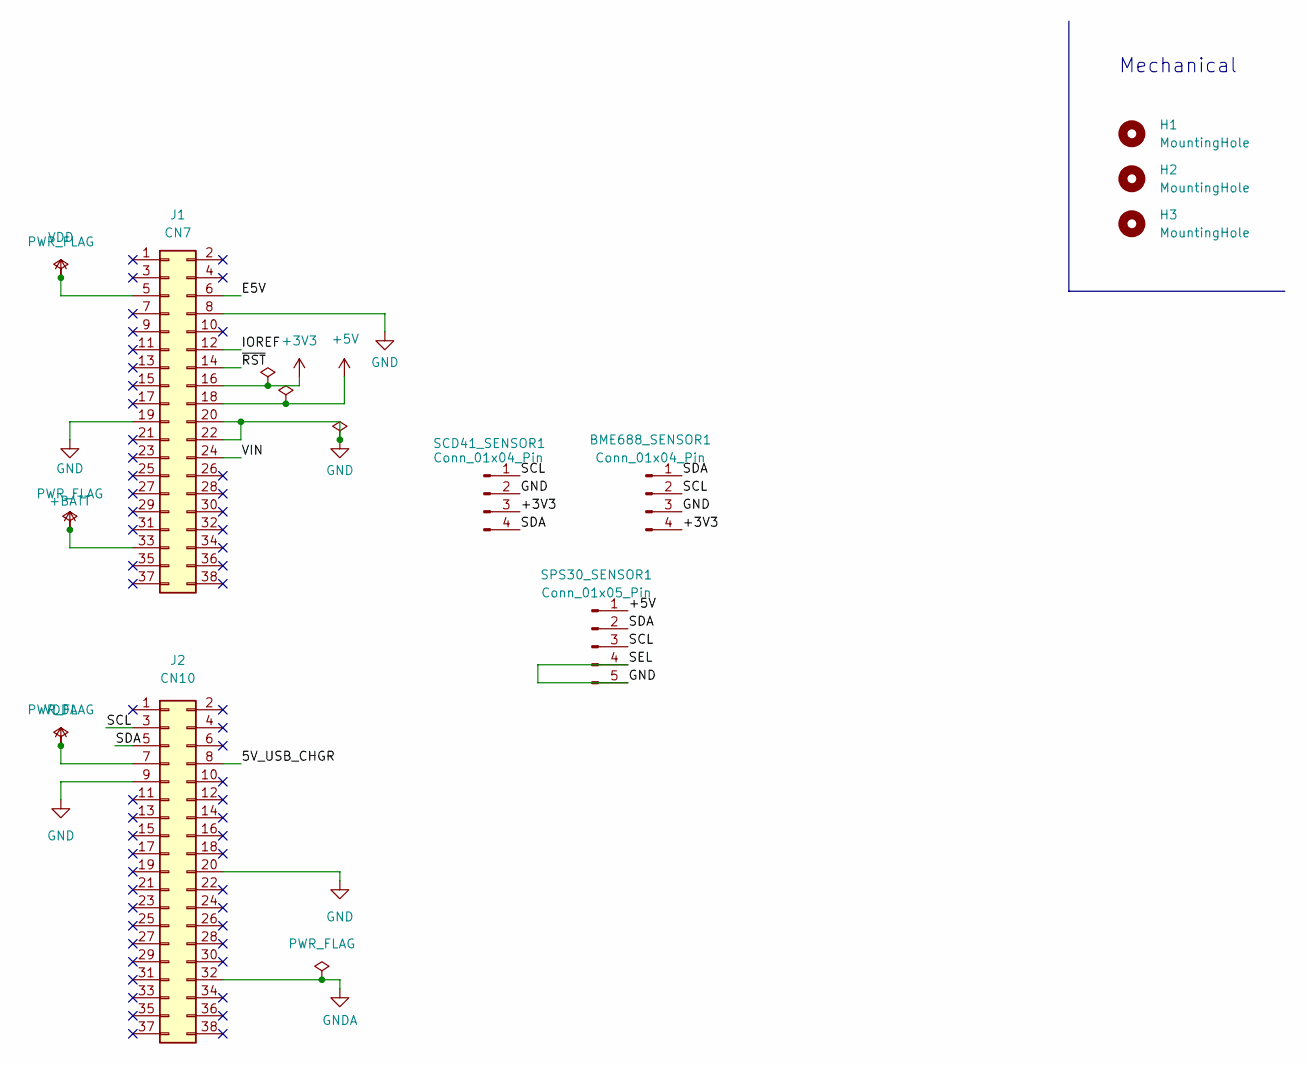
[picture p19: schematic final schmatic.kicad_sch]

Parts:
BME688_SENSOR1: Conn_01x04_Pin; PinHeader_1x04_P2.54mm_Vertical
H1, H2, H3: MountingHole; MountingHole_3.2mm_M3
J1: CN7; PinSocket_2x19_P2.54mm_Vertical
J2: CN10; PinSocket_2x19_P2.54mm_Vertical
SCD41_SENSOR1: Conn_01x04_Pin; PinHeader_1x04_P2.54mm_Vertical
SPS30_SENSOR1: Conn_01x05_Pin; PinHeader_1x05_P2.54mm_Vertical

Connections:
+3V3: BME688_SENSOR1.4, J1.16, SCD41_SENSOR1.3
+5V: J1.18, SPS30_SENSOR1.1
+BATT: J1.33
/5V_USB_CHGR: J2.8
/E5V: J1.6
/IOREF: J1.12
/SCL: BME688_SENSOR1.2, J2.3, SCD41_SENSOR1.1, SPS30_SENSOR1.3
/SDA: BME688_SENSOR1.1, J2.5, SCD41_SENSOR1.4, SPS30_SENSOR1.2
/VIN: J1.24
/~RST: J1.14
GND: BME688_SENSOR1.3, J1.8, J1.19, J1.20, J1.22, J2.9, J2.20, SCD41_SENSOR1.2, SPS30_SENSOR1.4, SPS30_SENSOR1.5
GNDA: J2.32
VDD: J1.5
VDDA: J2.7

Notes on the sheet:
Mechanical

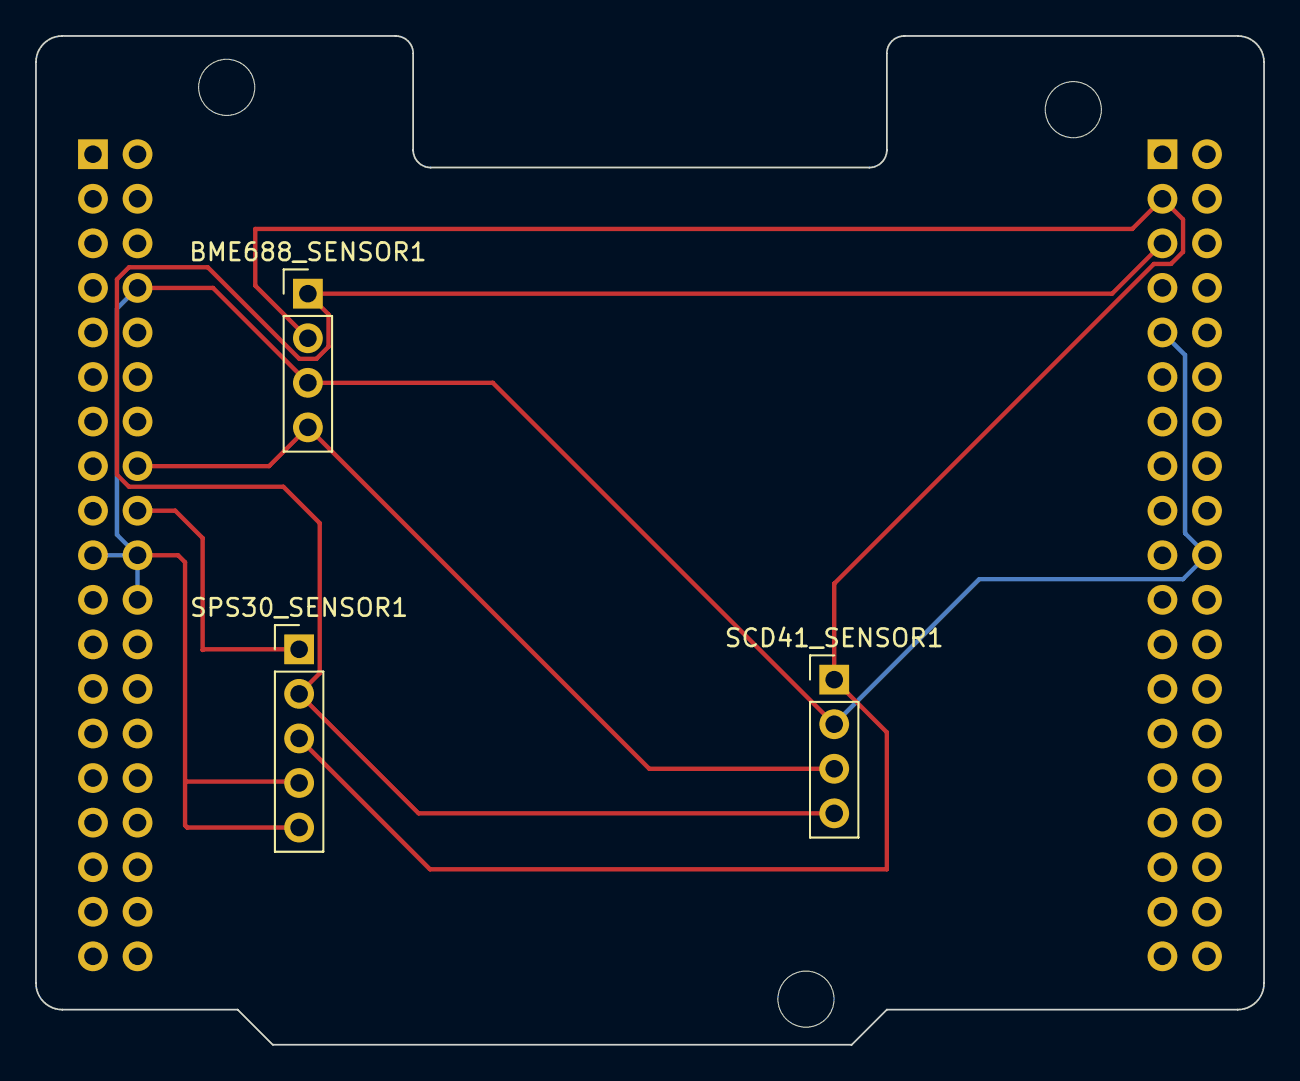
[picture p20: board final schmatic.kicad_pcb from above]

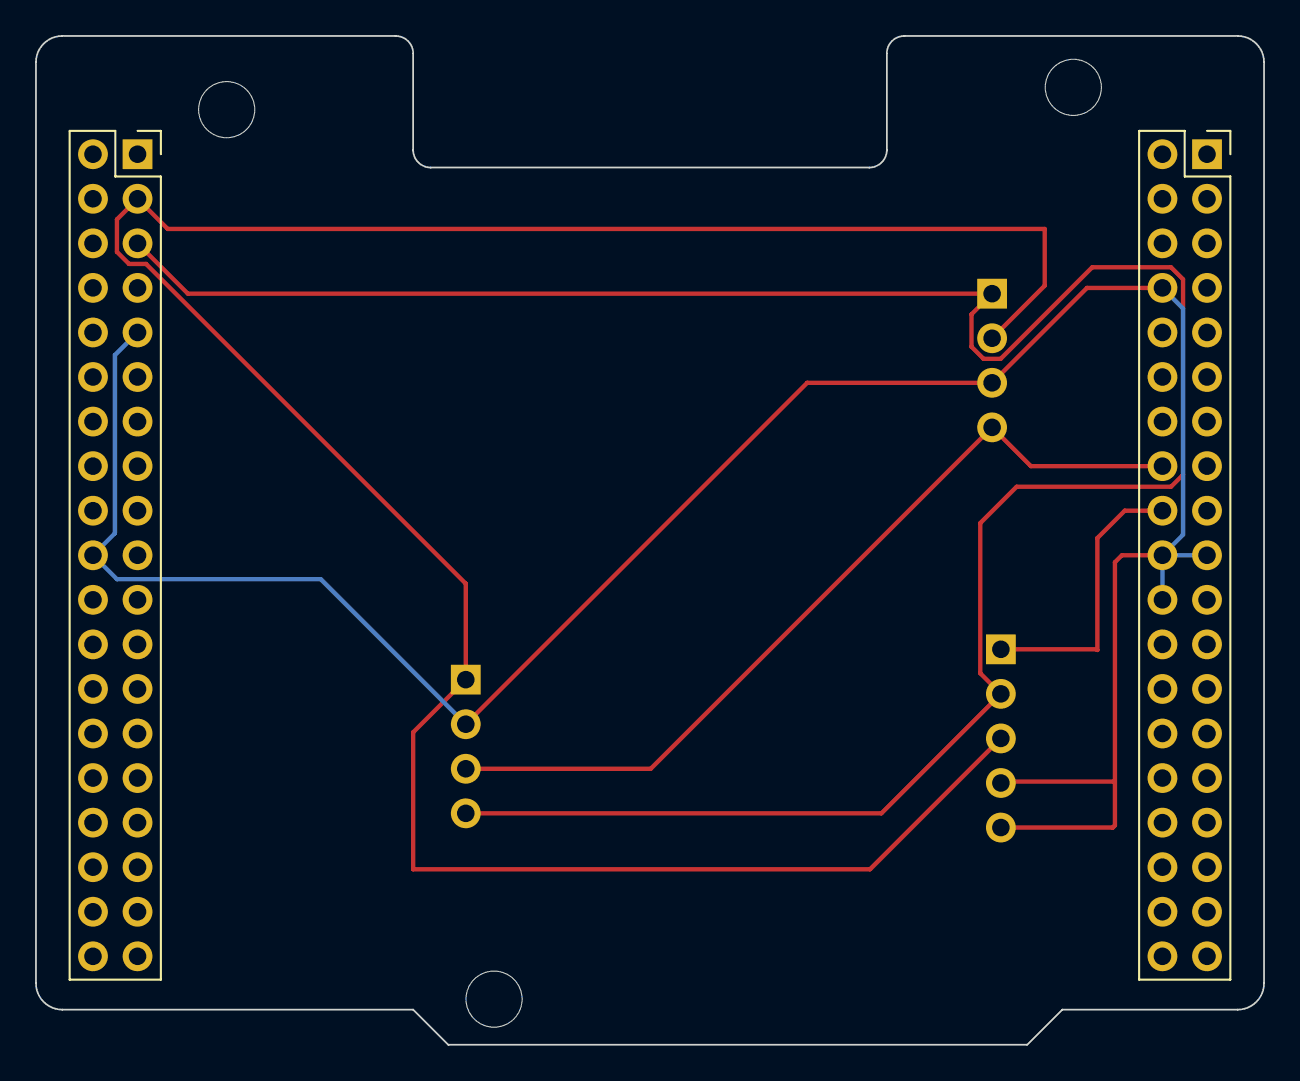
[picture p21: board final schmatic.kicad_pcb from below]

Board: 2 copper layers, 70.0 x 57.5 mm, 8 parts (2 on the bottom side), 5 nets.

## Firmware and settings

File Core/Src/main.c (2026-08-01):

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
/* Includes ------------------------------------------------------------------*/
#include "main.h"

/* USER CODE BEGIN Includes */
#include "bme68x_necessary_functions.h"  // Main header from the library
#include <stdio.h>

#include "scd4x_i2c.h"
#include "sensirion_i2c_hal.h"
#include <stdio.h>
#include "sps30_i2c.h"

/* USER CODE END Includes */

I2C_HandleTypeDef hi2c1;

RTC_HandleTypeDef hrtc;

UART_HandleTypeDef huart2;

/* USER CODE BEGIN PV */


//Data structure for BME688 sensor from the driver.
struct bme68x_data bme_data;


//Data structure for SCD41 sensor
typedef struct {
    uint16_t co2;           // CO₂ in ppm
    int32_t    temperature;   // °C
    int32_t    humidity;      // %RH
} scd41_data_t;

scd41_data_t scd41_data;



//Data structure for SPS30 sensor
typedef struct {
    float mc_1p0;   // Mass concentration PM1.0 [µg/m³]
    float mc_2p5;
    float mc_4p0;
    float mc_10p0;

    float nc_0p5;   // Number concentration [#/cm³]
    float nc_1p0;
    float nc_2p5;
    float nc_4p0;
    float nc_10p0;

    float typical_particle_size;  // µm
} sps30_data_t;

sps30_data_t sps30_data;






uint32_t last_frame_time = 0;
uint32_t reading_num = 0;

/* USER CODE END PV */

void SystemClock_Config(void);
static void MX_GPIO_Init(void);
static void MX_I2C1_Init(void);
static void MX_USART2_UART_Init(void);
static void MX_RTC_Init(void);
/* USER CODE BEGIN PFP */




int ei_add_sensor_reading(
    float co2,
    float temp,
    float humidity,
    float pressure,
    float gas_resistance,
    float pm1_0,
    float pm2_5,
    float pm4_0,
    float pm10_0,
    float pnc_0_5,
    float pnc_1_0,
    float pnc_2_5,
    float pnc_4_0,
    float pnc_10_0,
    float tps
);

/* USER CODE END PFP */

/**
  * @brief  The application entry point.
  * @retval int
  */
int main(void)
{

  /* MCU Configuration--------------------------------------------------------*/

  /* Reset of all peripherals, Initializes the Flash interface and the Systick. */
  HAL_Init();

  /* Configure the system clock */
  SystemClock_Config();

  /* Initialize all configured peripherals */
  MX_GPIO_Init();
  MX_I2C1_Init();
  MX_USART2_UART_Init();
  MX_RTC_Init();
  /* USER CODE BEGIN 2 */



// I2C SCANNER FUNCTION

  void I2C_Scan(I2C_HandleTypeDef *hi2c)
  {
      printf("Scanning I2C bus...\r\n");

      for (uint8_t i = 1; i < 127; i++)
      {
          if (HAL_I2C_IsDeviceReady(hi2c, (i << 1), 2, 10) == HAL_OK)
          {
              printf("Device found at 0x%02X\r\n", i);
          }
      }

      printf("Scan complete\r\n");
  }



  I2C_Scan(&hi2c1);




    if (bme68x_start(&bme_data, &hi2c1) != 0) {
        printf("BME688 initialization failed!\r\n");
        while(1);
    }
    printf("BME688 initialized successfully!\r\n");

    sensirion_i2c_hal_init();

        scd4x_init(0x62);                                 // Initialise sensor

        scd4x_stop_periodic_measurement();                // Safe start

        int16_t err = scd4x_start_periodic_measurement(); // Start continuous measurement
        if (err != 0) {
            printf("SCD41 initialisation failed! Error = %d\r\n", err);
            while(1);
        }

        printf("SCD41 initialised successfully!\r\n");
        printf("Waiting for first reading (~5-10 seconds)...\r\n\r\n");



        sps30_init(SPS30_I2C_ADDR_69);

        int16_t ret = sps30_wake_up_sequence();
            if (ret != 0) {
                printf("SPS30 wake-up failed: %d\r\n", ret);
            }



            ret = sps30_start_measurement(SPS30_OUTPUT_FORMAT_OUTPUT_FORMAT_FLOAT);
                if (ret != 0) {
                    printf("SPS30 start measurement failed! Error: %d\r\n", ret);
                } else {
                    printf("SPS30 initialised successfully (Float mode)\r\n");
                }


  /* USER CODE END 2 */

  /* Infinite loop */
  /* USER CODE BEGIN WHILE */


        HAL_Delay(15000);
          printf(",co2,temp,humidity,pressure,gas_resistance,pm1_0,pm2_5,pm4_0,pm10_0,pnc_0_5,pnc_1_0,pnc_2_5,pnc_4_0,pnc_10_0,tps\r\n");



  while (1)
  {
    /* USER CODE END WHILE */

    /* USER CODE BEGIN 3 */


	  uint32_t now = HAL_GetTick();


	      if (sps30_read_measurement_values_float(
	              &sps30_data.mc_1p0, &sps30_data.mc_2p5,
	              &sps30_data.mc_4p0, &sps30_data.mc_10p0,
	              &sps30_data.nc_0p5, &sps30_data.nc_1p0,
	              &sps30_data.nc_2p5, &sps30_data.nc_4p0,
	              &sps30_data.nc_10p0, &sps30_data.typical_particle_size) != 0)
	      {

	      }


	      bme68x_single_measure(&bme_data);

	        ei_add_sensor_reading(
	            (float)scd41_data.co2,
	            bme_data.temperature,
	            bme_data.humidity,
	            bme_data.pressure,
	            bme_data.gas_resistance,
	            sps30_data.mc_1p0,
	            sps30_data.mc_2p5,
	            sps30_data.mc_4p0,
	            sps30_data.mc_10p0,
	            sps30_data.nc_0p5,
	            sps30_data.nc_1p0,
	            sps30_data.nc_2p5,
	            sps30_data.nc_4p0,
	            sps30_data.nc_10p0,
	            sps30_data.typical_particle_size
	        );


	      if (now - last_frame_time >= 5000)   // 5 second MASTER FRAME
	      {
	          last_frame_time = now;

	          scd4x_get_data_ready_status(false);
	          scd4x_read_measurement(
	              &scd41_data.co2,
	              &scd41_data.temperature,
	              &scd41_data.humidity
	          );


	          uint32_t ms = now;
	          uint32_t seconds = ms / 1000;
	          uint32_t minutes = seconds / 60;
	          uint32_t hours   = minutes / 60;

	          seconds %= 60;
	          minutes %= 60;
	          hours %= 24;


		       // printf("%02lu:%02lu:%02lu, %lu, %4u, %.2f, %.2f, %.2f, %.2f, %.2f, %.2f, %.2f, %.2f, %.2f, %.2f, %.2f, %.2f, %.2f, %.2f\r\n",
				        printf(",%4u, %.2f, %.2f, %.2f, %.2f, %.2f, %.2f, %.2f, %.2f, %.2f, %.2f, %.2f, %.2f, %.2f, %.2f\r\n",

		                       scd41_data.co2,
		                       bme_data.temperature, bme_data.humidity, bme_data.pressure,bme_data.gas_resistance,
		                          sps30_data.mc_1p0, sps30_data.mc_2p5,
		                          sps30_data.mc_4p0, sps30_data.mc_10p0,
		                          sps30_data.nc_0p5, sps30_data.nc_1p0,
		                          sps30_data.nc_2p5, sps30_data.nc_4p0,
		                          sps30_data.nc_10p0, sps30_data.typical_particle_size);

//   TIME | # | CO2 | TEMP | HUMIDITY |PRESSURE | GAS RESISTANCE | PM1.0 | PM2.5| PM4.0 | PM10.0| PNC 0.5 | PNC 1.0 | PNC 2.5 | PNC 4.0 |PNC 10.0| TPS





	      }











	/*




	  int16_t ret = sps30_read_measurement_values_float(
	                          &sps30_data.mc_1p0, &sps30_data.mc_2p5,
	                          &sps30_data.mc_4p0, &sps30_data.mc_10p0,
	                          &sps30_data.nc_0p5, &sps30_data.nc_1p0,
	                          &sps30_data.nc_2p5, &sps30_data.nc_4p0,
	                          &sps30_data.nc_10p0, &sps30_data.typical_particle_size);

	          if (ret != 0) {
	              printf("SPS30 read error: %d\r\n", ret);
	          }





	    bme68x_single_measure(&bme_data);


	    scd4x_get_data_ready_status(false);
	    scd4x_read_measurement(&scd41_data.co2, &scd41_data.temperature, &scd41_data.humidity);





	        uint32_t ms = HAL_GetTick();

	        uint32_t seconds = ms / 1000;
	        uint32_t minutes = seconds / 60;
	        uint32_t hours   = minutes / 60;

	        seconds = seconds % 60;
	        minutes = minutes % 60;
	        hours   = hours % 24;

	        printf(" %02lu:%02lu:%02lu | #%lu | CO2= %4uppm | TEMP= %.2f°C | HUMIDITY= %.2f%% |PRESSURE = %.2f | GAS RESISTANCE = %.2f | PM1.0= %.2f | PM2.5= %.2f | PM4.0= %.2f | PM10.0= %.2f | PNC 0.5= %.2f | PNC 1.0= %.2f | PNC 2.5= %.2f | PNC 4.0= %.2f |PNC 10.0= %.2f  | TPS= %.2f \r\n",

	        	       hours, minutes, seconds,
	        		reading_num++,
	                       scd41_data.co2,
	                       bme_data.temperature, bme_data.humidity, bme_data.pressure,bme_data.gas_resistance,
	                          sps30_data.mc_1p0, sps30_data.mc_2p5,
	                          sps30_data.mc_4p0, sps30_data.mc_10p0,
	                          sps30_data.nc_0p5, sps30_data.nc_1p0,
	                          sps30_data.nc_2p5, sps30_data.nc_4p0,
	                          sps30_data.nc_10p0, sps30_data.typical_particle_size);


*/


  }

  /* USER CODE END 3 */
}

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
/* USER CODE BEGIN 4 */
int _write(int file, char *ptr, int len)
{
    HAL_UART_Transmit(&huart2, (uint8_t*)ptr, len, HAL_MAX_DELAY);
    return len;
}

/* USER CODE END 4 */
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


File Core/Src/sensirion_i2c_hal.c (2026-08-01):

/*
 * Copyright (c) 2018, Sensirion AG
 * All rights reserved.
 *
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
 * * Neither the name of Sensirion AG nor the names of its
 *   contributors may be used to endorse or promote products derived from
 *   this software without specific prior written permission.
 *
 * THIS SOFTWARE IS PROVIDED BY THE COPYRIGHT HOLDERS AND CONTRIBUTORS "AS IS"
 * AND ANY EXPRESS OR IMPLIED WARRANTIES, INCLUDING, BUT NOT LIMITED TO, THE
 * IMPLIED WARRANTIES OF MERCHANTABILITY AND FITNESS FOR A PARTICULAR PURPOSE
 * ARE DISCLAIMED. IN NO EVENT SHALL THE COPYRIGHT HOLDER OR CONTRIBUTORS BE
 * LIABLE FOR ANY DIRECT, INDIRECT, INCIDENTAL, SPECIAL, EXEMPLARY, OR
 * CONSEQUENTIAL DAMAGES (INCLUDING, BUT NOT LIMITED TO, PROCUREMENT OF
 * SUBSTITUTE GOODS OR SERVICES; LOSS OF USE, DATA, OR PROFITS; OR BUSINESS
 * INTERRUPTION) HOWEVER CAUSED AND ON ANY THEORY OF LIABILITY, WHETHER IN
 * CONTRACT, STRICT LIABILITY, OR TORT (INCLUDING NEGLIGENCE OR OTHERWISE)
 * ARISING IN ANY WAY OUT OF THE USE OF THIS SOFTWARE, EVEN IF ADVISED OF THE
 * POSSIBILITY OF SUCH DAMAGE.
 */




#include "sensirion_common.h"
#include "sensirion_config.h"
#include "sensirion_i2c_hal.h"
#include "main.h"
extern I2C_HandleTypeDef hi2c1;
/**
 * Create new I2C instance. You may also use a different interface, e.g. hi2c2,
 * depending on your CubeMX configuration
 */


/**
 * Initialize all hard- and software components that are needed for the I2C
 * communication.
 */
void sensirion_i2c_hal_init(void) {
 
}

/**
 * Release all resources initialized by sensirion_i2c_hal_init().
 */
void sensirion_i2c_hal_free(void) {
}

/**
 * Execute one read transaction on the I2C bus, reading a given number of bytes.
 * If the device does not acknowledge the read command, an error shall be
 * returned.
 *
 * @param address 7-bit I2C address to read from
 * @param data    pointer to the buffer where the data is to be stored
 * @param count   number of bytes to read from I2C and store in the buffer
 * @returns 0 on success, error code otherwise
 */
int8_t sensirion_i2c_hal_read(uint8_t address, uint8_t* data, uint8_t count) {
return (HAL_I2C_Master_Receive(&hi2c1, 
                                   (address << 1),      // 7-bit to 8-bit address
                                   data, 
                                   count, 
                                   150) == HAL_OK) ? 0 : -1;
}

/**
 * Execute one write transaction on the I2C bus, sending a given number of
 * bytes. The bytes in the supplied buffer must be sent to the given address. If
 * the slave device does not acknowledge any of the bytes, an error shall be
 * returned.
 *
 * @param address 7-bit I2C address to write to
 * @param data    pointer to the buffer containing the data to write
 * @param count   number of bytes to read from the buffer and send over I2C
 * @returns 0 on success, error code otherwise
 */
int8_t sensirion_i2c_hal_write(uint8_t address, const uint8_t* data,
                               uint8_t count) {
return (HAL_I2C_Master_Transmit(&hi2c1, 
                                    (address << 1),     // 7-bit to 8-bit address
                                    (uint8_t*)data, 
                                    count, 
                                    150) == HAL_OK) ? 0 : -1;
}

/**
 * Sleep for a given number of microseconds. The function should delay the
 * execution for at least the given time, but may also sleep longer.
 *
 * @param useconds the sleep time in microseconds
 */
void sensirion_i2c_hal_sleep_usec(uint32_t useconds) {
    uint32_t ms = (useconds + 999U) / 1000U;   // convert us to ms
    if (ms == 0) ms = 1;
    HAL_Delay(ms);

}

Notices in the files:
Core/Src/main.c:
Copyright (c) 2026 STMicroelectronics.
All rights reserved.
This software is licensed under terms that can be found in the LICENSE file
